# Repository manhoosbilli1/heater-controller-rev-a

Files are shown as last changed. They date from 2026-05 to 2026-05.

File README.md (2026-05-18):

# HEATER CONTROLLER REV_A

Battery-powered heater controller, 10 A switching, hierarchical schematic (ATtiny + OLED + dual-battery taps)

## At a Glance

- **Status**: Routed
- **Board size**: 47.24 x 45.82 mm
- **Layers**: 2
- **Components**: 75
- **Key ICs**:
  - U1: ATtiny3216-S
  - U2: DS18B20U
  - U3: TP4056
  - U4: INA234AxYBJ
  - U5,U6: TPS73001SF6
  - U7: TPS22997RYZR

## Schematic

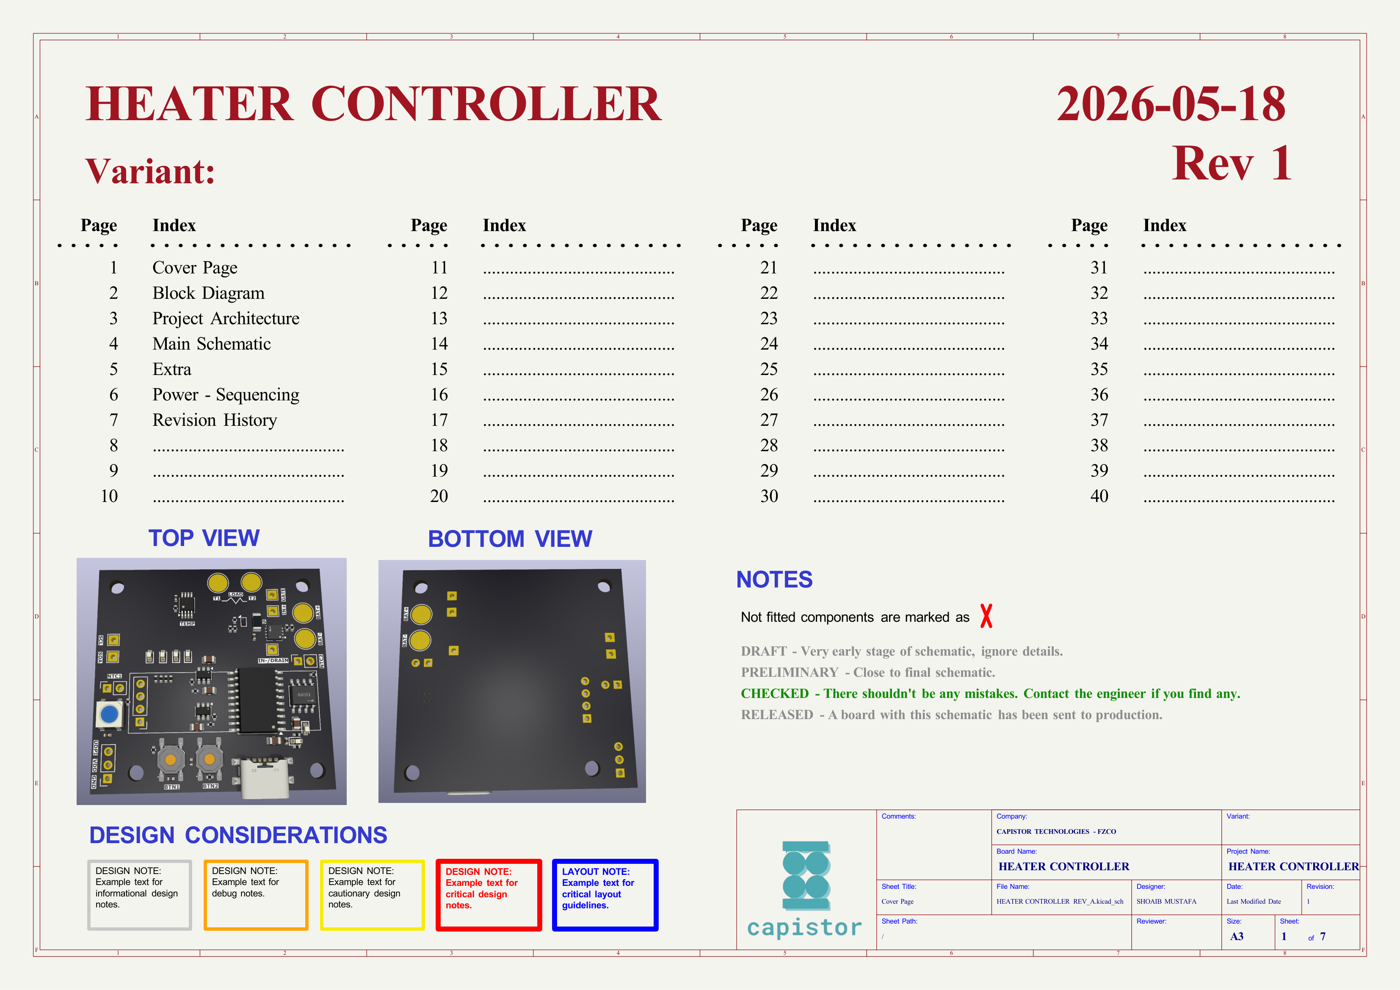
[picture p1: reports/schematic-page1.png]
Schematic


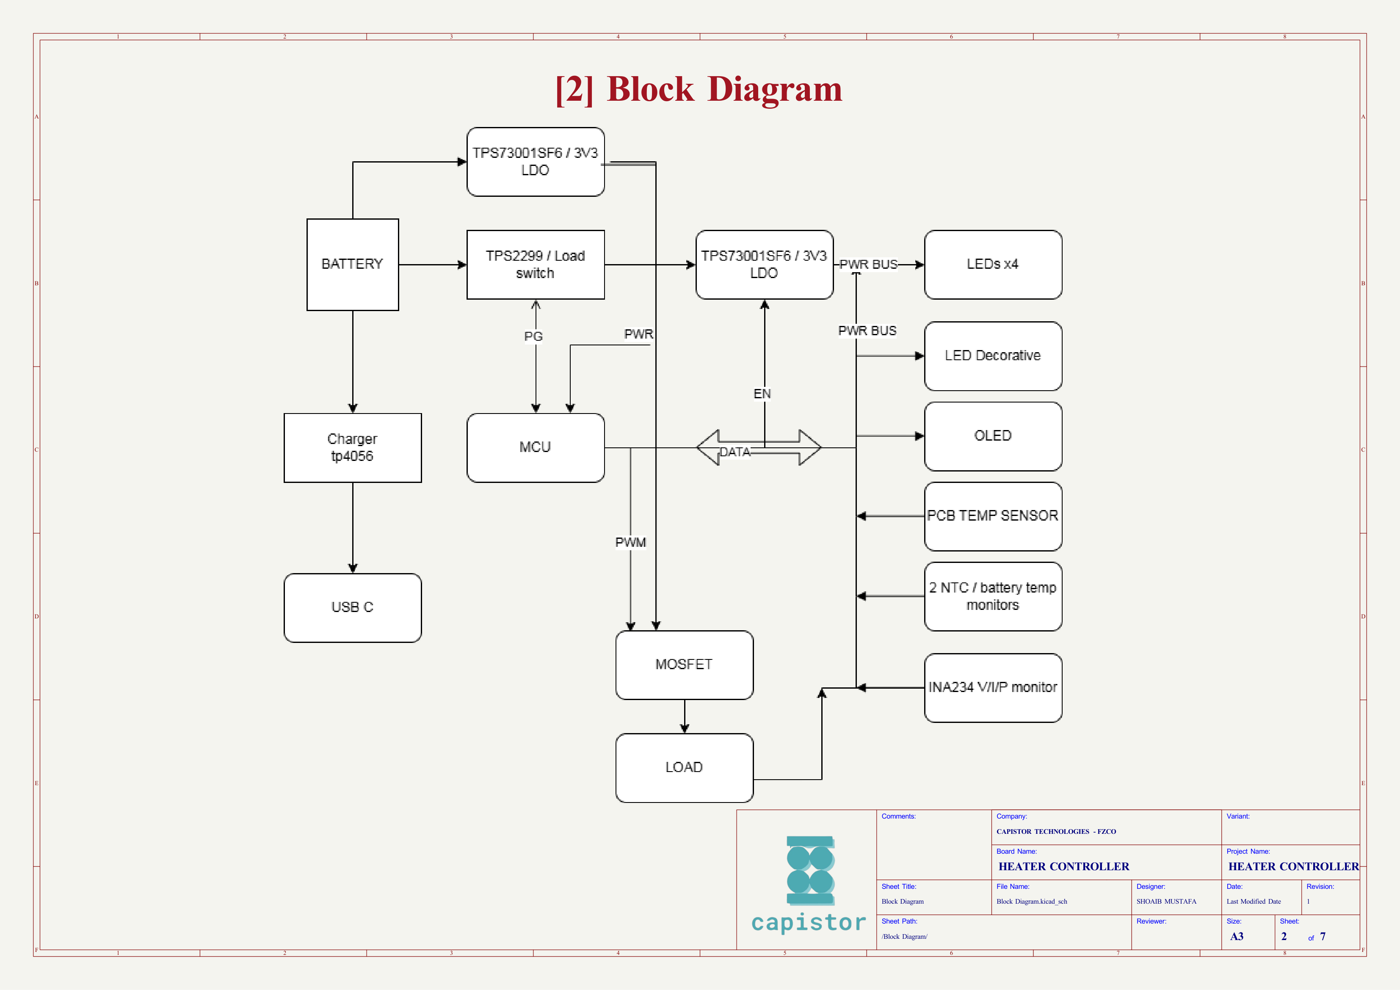
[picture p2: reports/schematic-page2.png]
Schematic


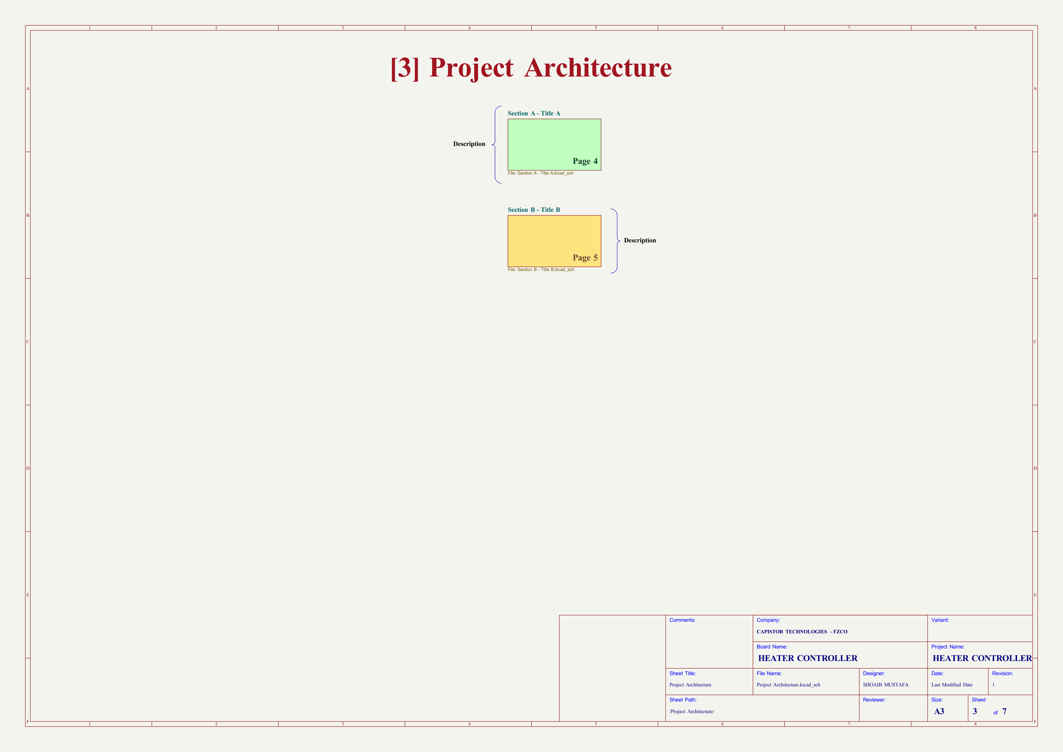
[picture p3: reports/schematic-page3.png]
Schematic


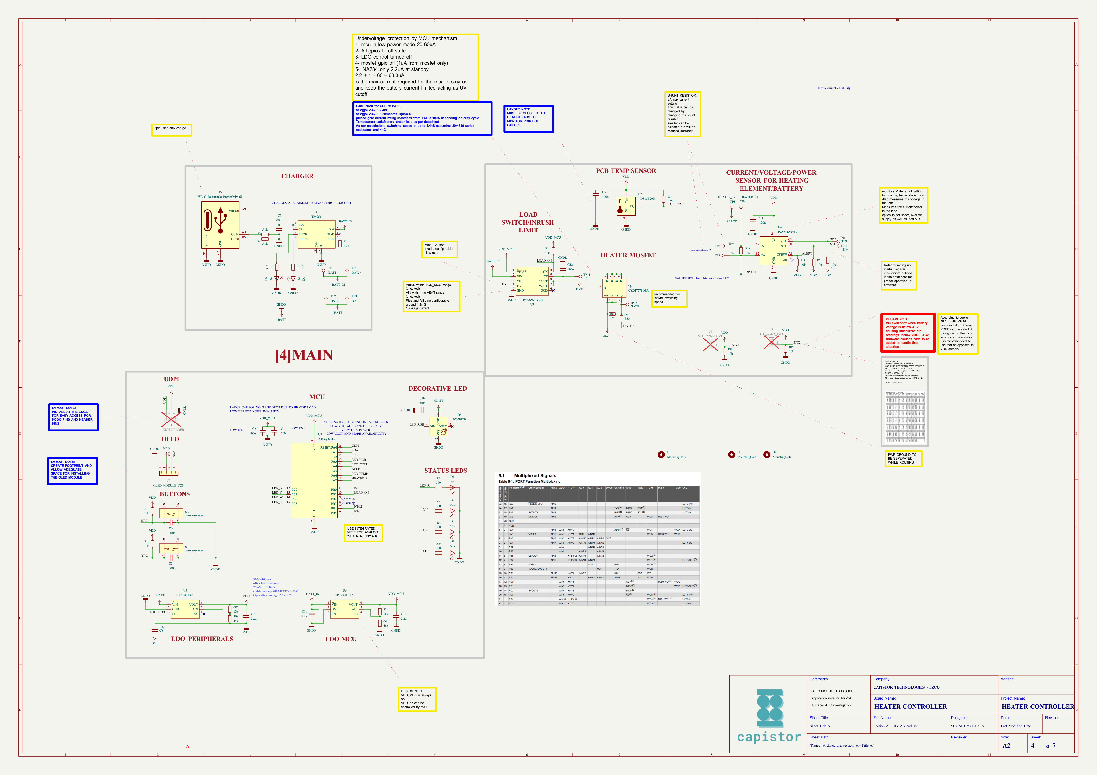
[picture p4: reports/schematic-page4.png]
Schematic


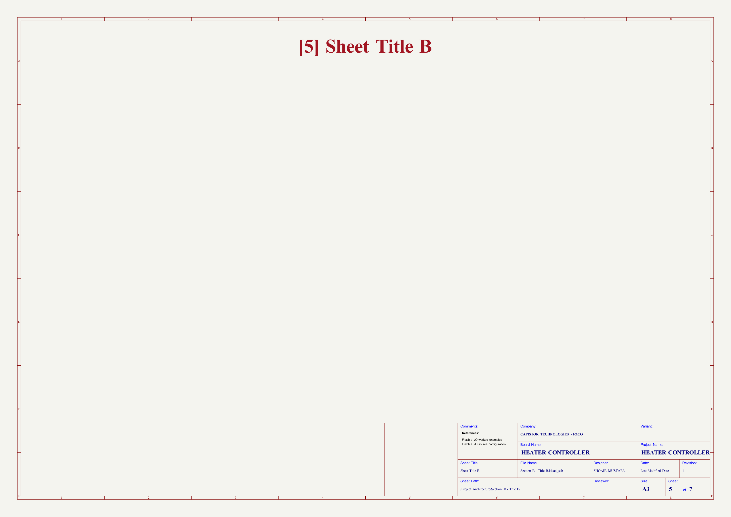
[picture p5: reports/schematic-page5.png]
Schematic


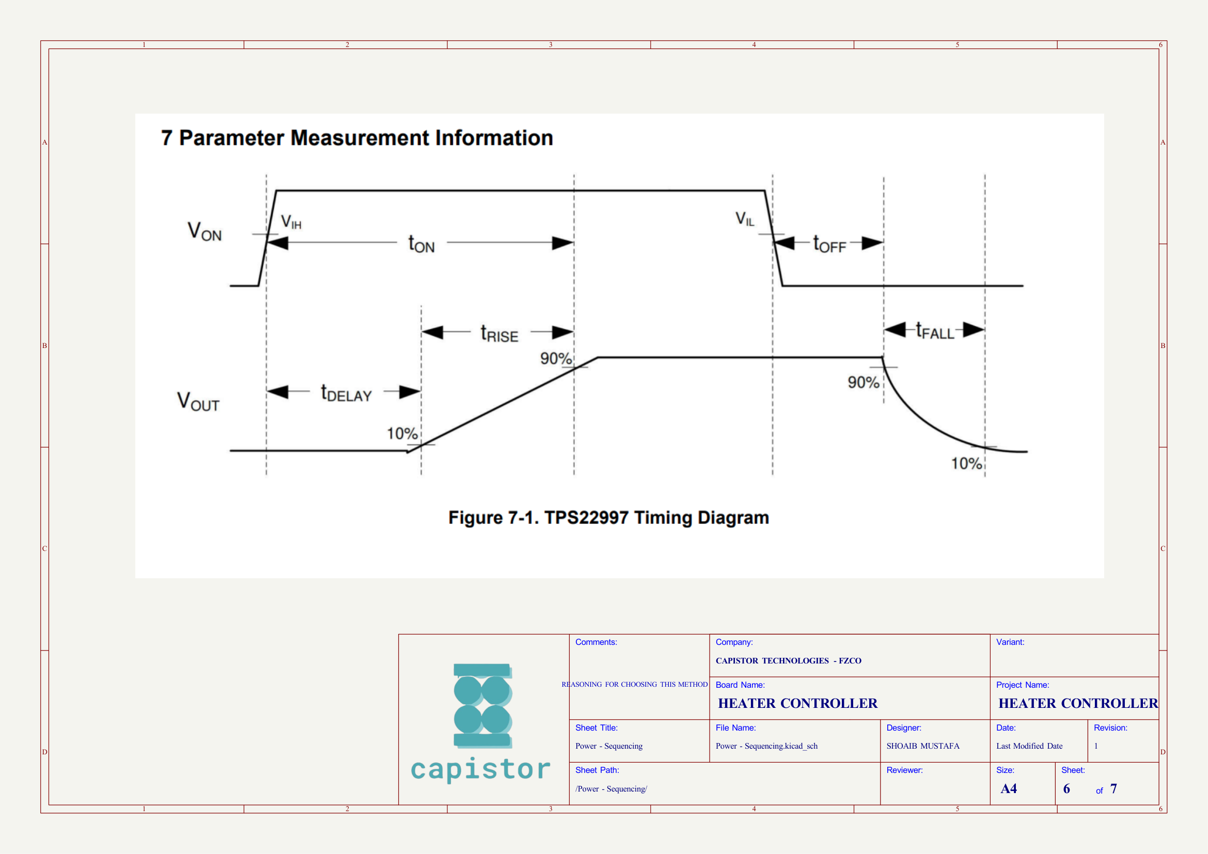
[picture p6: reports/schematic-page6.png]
Schematic


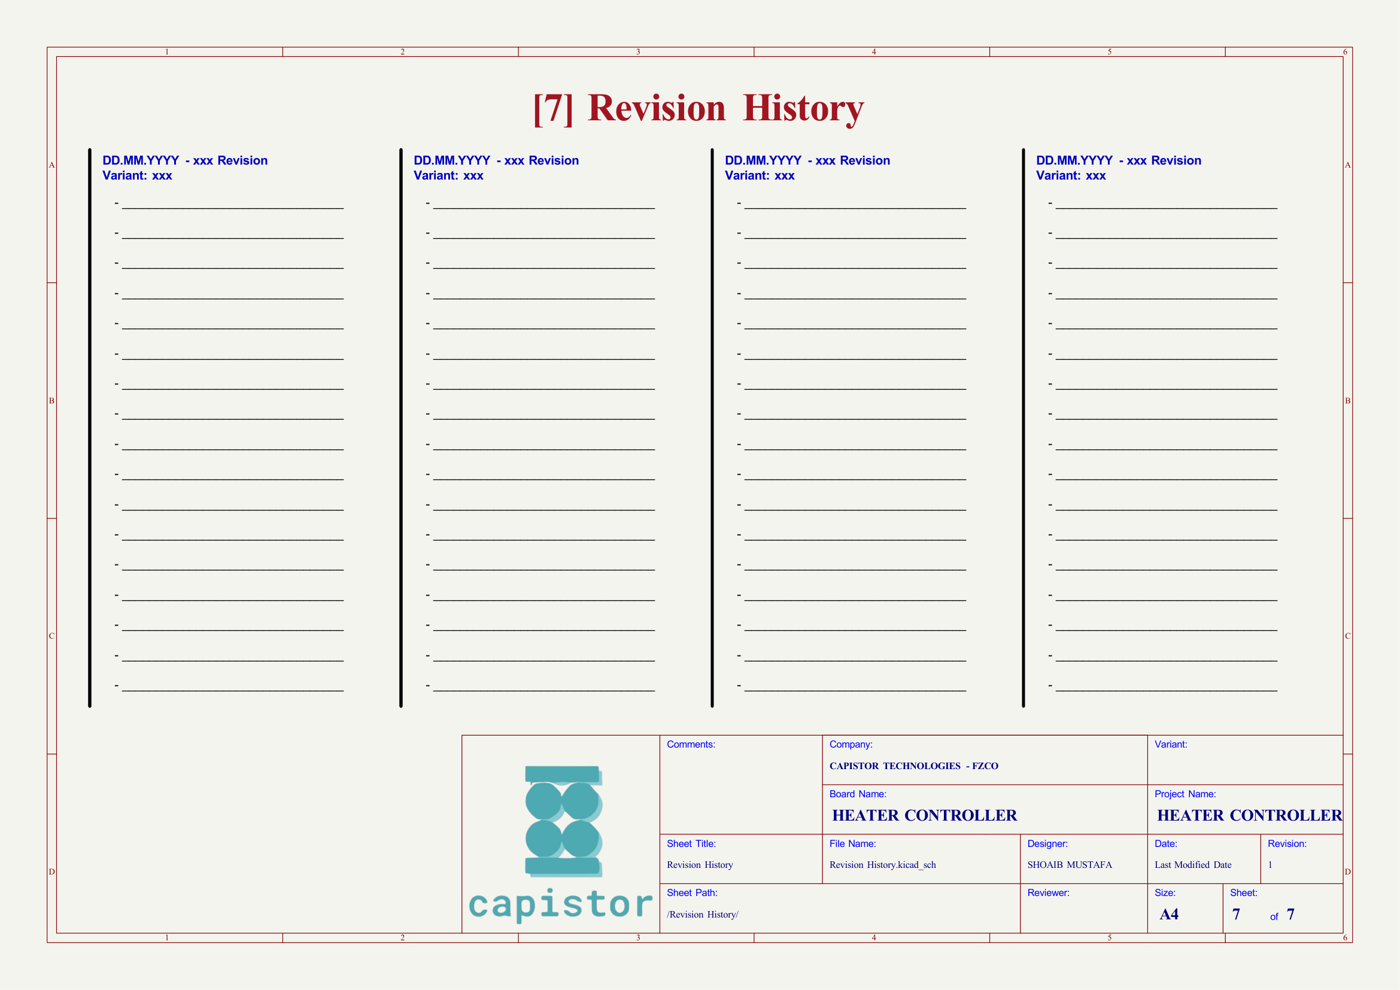
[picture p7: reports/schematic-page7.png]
Schematic


Full PDF: [reports/schematic.pdf](reports/schematic.pdf)

## Component Roles

- **ATtiny** (in hierarchical sub-sheets) - main MCU; reads temperature and PWM-drives the heater MOSFET
- **CSD17578Q3A** (Q2) - 30 V, 100 A, 1.8 m-Ohm N-channel MOSFET; switches the heater load directly (low Rds(on) keeps conduction losses small at 10 A)
- **WS2812B** (D5) - status RGB LED
- **USB-C** charging input (power-only, 6P)
- **Dual battery taps** (TP1-TP4: BAT1+, BAT1-, BAT2+, BAT2-) for parallel/series battery configurations
- **Heater output taps** (TP5/TP6: HEATER_T1, HEATER_T2)
- Hierarchical schematic split across: Block Diagram, Project Architecture, Power-Sequencing, and Section A/B sub-sheets

## PCB

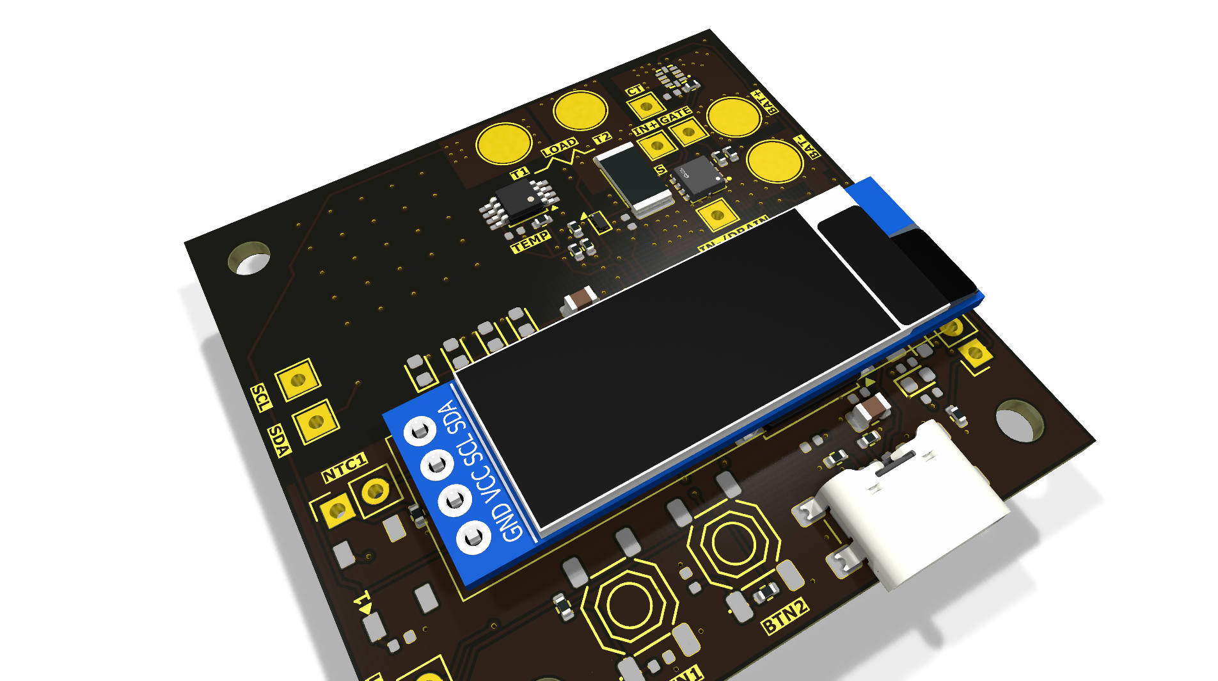
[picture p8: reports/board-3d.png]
3D top


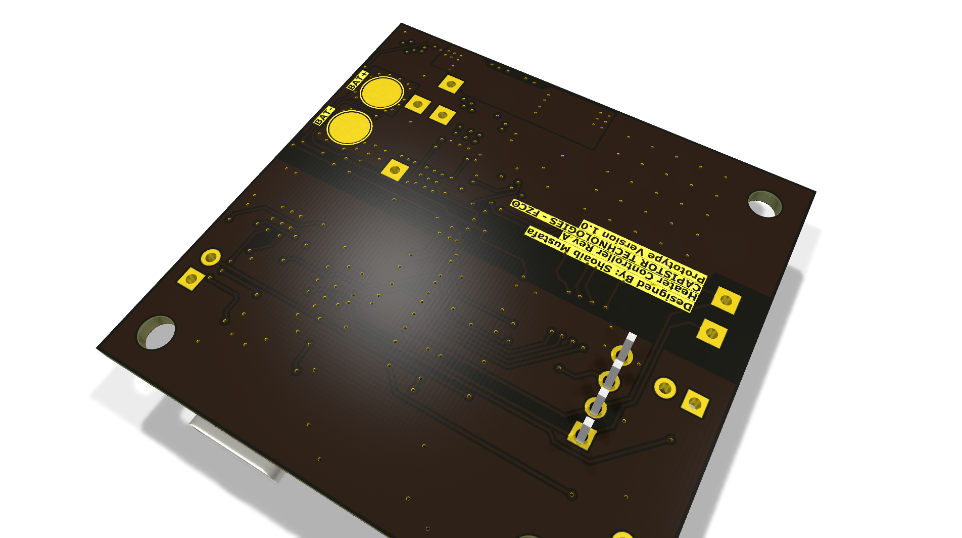
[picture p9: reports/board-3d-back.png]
3D bottom


**Top copper**

PCB top

**Bottom copper**

PCB bottom

## Bill of Materials

| Refs | Value | Footprint | Qty | MPN | LCSC |
|---|---|---|----:|-----|---|
| C1,C3-C7,C10,C12 | 100n | PCM_JLCPCB:C_0402 | 8 |  |  |
| C2 | 100u | Capacitor_SMD:C_0805_2012Metric | 1 |  | [C141660](https://www.lcsc.com/product-detail/_C141660.html) |
| C8,C9,C11,C13 | 2.2u | Capacitor_SMD:C_0805_2012Metric | 4 |  |  |
| D1,D6,D7 | Red | PCM_JLCPCB:D_0603 | 3 |  | [C2286](https://www.lcsc.com/product-detail/_C2286.html) |
| D2 | White | PCM_JLCPCB:D_0603 | 1 |  | [C2290](https://www.lcsc.com/product-detail/_C2290.html) |
| D3 | Yellow | PCM_JLCPCB:D_0603 | 1 |  | [C89811](https://www.lcsc.com/product-detail/_C89811.html) |
| D4 | Green | PCM_JLCPCB:D_0603 | 1 |  | [C122984](https://www.lcsc.com/product-detail/_C122984.html) |
| D5 | WS2812B | PCM_JLCPCB:LED_WS2812B_PLCC4_5.0x5.0mm_P3.2mm | 1 |  | [C22461793](https://www.lcsc.com/product-detail/_C22461793.html) |
| J5 | USB_C_Receptacle_PowerOnly_6P | Connector_USB:USB_C_Receptacle_GCT_USB4135-GF-A_6P_TopMnt_Horizontal | 1 |  |  |
| Q2 | CSD17578Q3A | mosfet_ti:PDFN3333-8_L3.1-W3.2-P0.65-LS3.4-BL | 1 |  |  |
| R1 | 4.7k | Resistor_SMD:R_0402_1005Metric | 1 |  |  |
| R2 | 1.2k | Resistor_SMD:R_0402_1005Metric | 1 |  |  |
| R3,R4 | 5.1k | Resistor_SMD:R_0402_1005Metric | 2 |  |  |
| R5,R6,R11,R12,R14,R15,R18,R19,R21,R24,R25 | 10k | Resistor_SMD:R_0402_1005Metric | 11 |  |  |
| R7-R10 | 330 | PCM_JLCPCB:R_0402 | 4 |  |  |
| R13 | 8m | Resistor_SMD:R_2512_6332Metric | 1 |  | [C2904240](https://www.lcsc.com/product-detail/_C2904240.html) |
| R16,R17 | 1k | PCM_JLCPCB:R_0402 | 2 |  |  |
| R20,R26 | 46k | Resistor_SMD:R_0402_1005Metric | 2 |  | [C3016791](https://www.lcsc.com/product-detail/_C3016791.html) |
| R23 | 330 | Resistor_SMD:R_0402_1005Metric | 1 |  |  |
| S1,S3 | Tactile Button, 160gf | PCM_JLCPCB:SW-SMD_4P-L5.1-W5.1-P3.70-LS6.5-TL-2 | 2 |  | [C318884](https://www.lcsc.com/product-detail/_C318884.html) |
| TP1 | BAT2+ | TestPoint:TestPoint_Pad_D4.0mm | 1 |  |  |
| TP2 | BAT2- | TestPoint:TestPoint_Pad_D4.0mm | 1 |  |  |
| TP3 | BAT1+ | TestPoint:TestPoint_Pad_D4.0mm | 1 |  |  |
| TP4 | BAT1- | TestPoint:TestPoint_Pad_D4.0mm | 1 |  |  |
| TP5 | HEATER_T2 | TestPoint:TestPoint_Pad_D4.0mm | 1 |  |  |
| TP6 | HEATER_T1 | TestPoint:TestPoint_Pad_D4.0mm | 1 |  |  |
| TP7,TP9,TP10 | IN+ | TestPoint:TestPoint_THTPad_2.0x2.0mm_Drill1.0mm | 3 |  |  |
| TP8 | IN- | TestPoint:TestPoint_THTPad_2.0x2.0mm_Drill1.0mm | 1 |  |  |
| TP11 | CT | TestPoint:TestPoint_THTPad_2.0x2.0mm_Drill1.0mm | 1 |  |  |
| TP12 | GATE | TestPoint:TestPoint_THTPad_2.0x2.0mm_Drill1.0mm | 1 |  |  |
| U1 | ATtiny3216-S | Package_SO:SOIC-20W_7.5x12.8mm_P1.27mm | 1 |  |  |
| U2 | DS18B20U | Package_SO:MSOP-8_3x3mm_P0.65mm | 1 |  |  |
| U3 | TP4056 | PCM_JLCPCB:ESOP-8_L4.9-W3.9-P1.27-LS6.0-BL-EP | 1 |  | [C16581](https://www.lcsc.com/product-detail/_C16581.html) |
| U4 | INA234AxYBJ | Package_BGA:Texas_DSBGA-8_0.705x1.468mm_Layout2x4_P0.4mm | 1 |  |  |
| U5,U6 | TPS73001SF6 | tps73001sf6:SOT-23-6_L2.9-W1.6-P0.95-LS2.8-BL | 2 |  |  |
| U7 | TPS22997RYZR | load_switch:UQFN-10_L2.0-W1.5-P0.50-TL | 1 |  |  |

_26 of 36 line items don't have an LCSC code in the schematic - search [LCSC](https://www.lcsc.com/) or [JLC parts search](https://jlcsearch.tscircuit.com/) by MPN or footprint when sourcing._

## Files

- `HEATER CONTROLLER REV_A.kicad_pro` - KiCad project
- `HEATER CONTROLLER REV_A.kicad_sch` - schematic source
- `HEATER CONTROLLER REV_A.kicad_pcb` - PCB layout source
- `reports/schematic.pdf` - full schematic (printable)
- `reports/bom.csv` - bill of materials
- `reports/pcb-top.svg`, `reports/pcb-bottom.svg` - copper artwork
- `reports/board-stats.json` - KiCad-generated board statistics

---

_Renders and metadata auto-generated by `Backup-KiCadProject.ps1` using KiCad 10.0._

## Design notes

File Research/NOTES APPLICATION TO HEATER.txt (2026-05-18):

MOSFET NOTES APPLICATION TO HEATER CONTROLLER 

- MUST be driven by low impedence source capable of sourcing and sinking current. does that mean it should be able to sink eqv charge by the mcu? 
- switching speeds are mostly high for all mosfets depended on carriers travel across band gap
- ON constant current not needed. just enough to charge the capacitors. 
- interested current conduction electrode (gate?) is isolated from the conducting path? yet because of the discharge resistor gate is not truly isolated. put optocoupler in between to achieve galvanic isolation. 

ISOLATION OF MCU AND HEATER 
- NO GALVANIC ISOLATION IS NEEDED. IT IS ONLY REQUIRE TO KEEP IT ELECTRICALLY ISOLATED
-For this the return current from the heater 10A should not flow through the mcu ground -for this we keep the mcu
-ground relatively higher resistance meaning short traces and the heater ground thicker

Exploring STAR ground technique to achieve electrical isolation of the ground:
-not applicable as it deals with providing a common ground point at same potential to various modules being connected to a common ground. 

Addressing the noise occurring due to switching 10A of current in the PCB:
- 

Addressing the thermal conductivity of the PCB traces and providing adequate dimensions for optimum performance: 
- Strategically place Thermal vias 
- consider inner planes just for heat transfer 
- consider gold plated pads instead of HASL for better connectivity and heat resistance
- consider focusing on junction temperature of each active component
- Consider location of heat source
- Consider creating a gradient to allow for natural heat flow from hot to cold
- Thermal resistance of PCB is determined by the material properties of the substrate and arrangement of copper elements in the board
- Keep high current traces short, wide for least thermal resistance and least voltage drop 
- consider measuring pcb thermal conductivity by guarded hot plate method; measuring temp of hot and cold surface of the pcb 
- Can also consider 3-omega measurement but a bit more involved
- Layer stackup can play a role in it. 
- Thermal resistance measurements can be carried out once the PCB is ordered as a prototype to improve in the next iteration 

power, inrush calculations and reasonings behind it. 

at 10Khz what would be the the saturation on the mosfet at 3.3V?
What would be the Rds(on) at that point? 
What is the inrush current of the heater material
What is the power dessipawted at that point

I(inrush current ) = Vmax / cold resistance = 4.2 / 0.199 ohm = 21A 

power drawn P = (Inrush current)^2 * (rdson + shunt resistor + material_resistance) = 21^2 * (0.199 + 0.004 + 0.004) = 1.65

Avoiding thermal runaway:
usually seen in applications powered by constant current source whereas the battery is a constant voltage source, as the temperature rises the resistance rises, as resistance rises Temperature of the trace rises, because current is constant more heat is generated which further increases the resistance and hence a condition is reached where the traces burn or explode: a thermal runaway

finding out if mosfet can handle the peak current P = Vds * Id = 4.2 * 21 = 88 W?

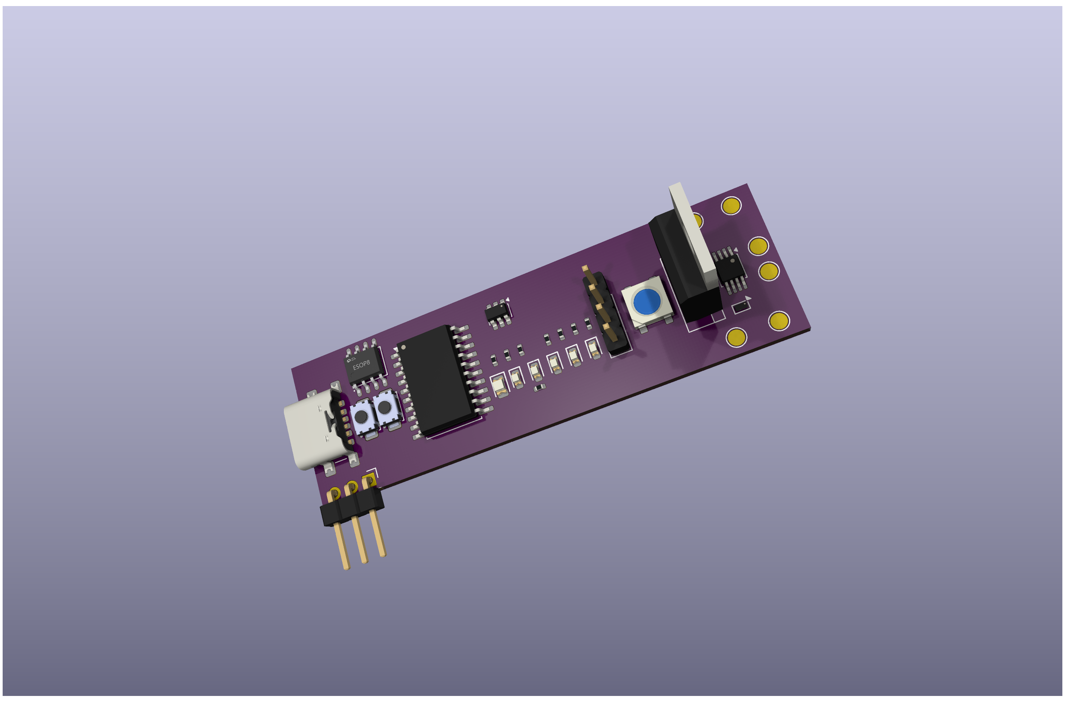
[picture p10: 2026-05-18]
Images/PRELIMINARY PLACEMENT.png

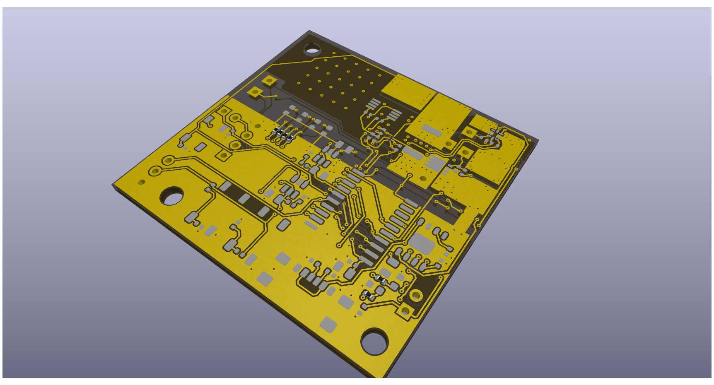
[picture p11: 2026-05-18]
Images/HEATER CONTROLLER REV_A_Checked_prototype_v1.0_front_copper_plane_without_models.png

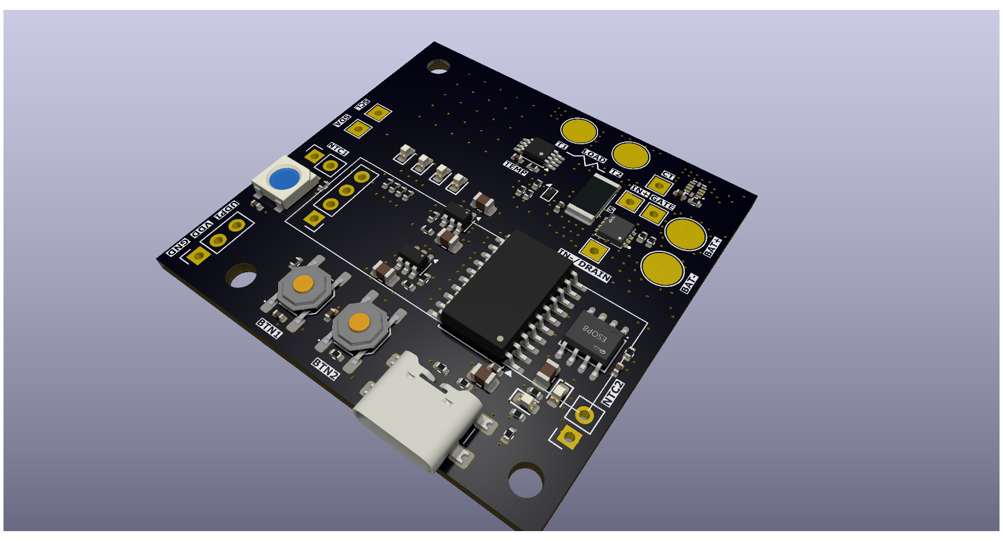
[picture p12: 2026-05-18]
Images/HEATER CONTROLLER REV_A_Checked_prototype_v1.0_front.png

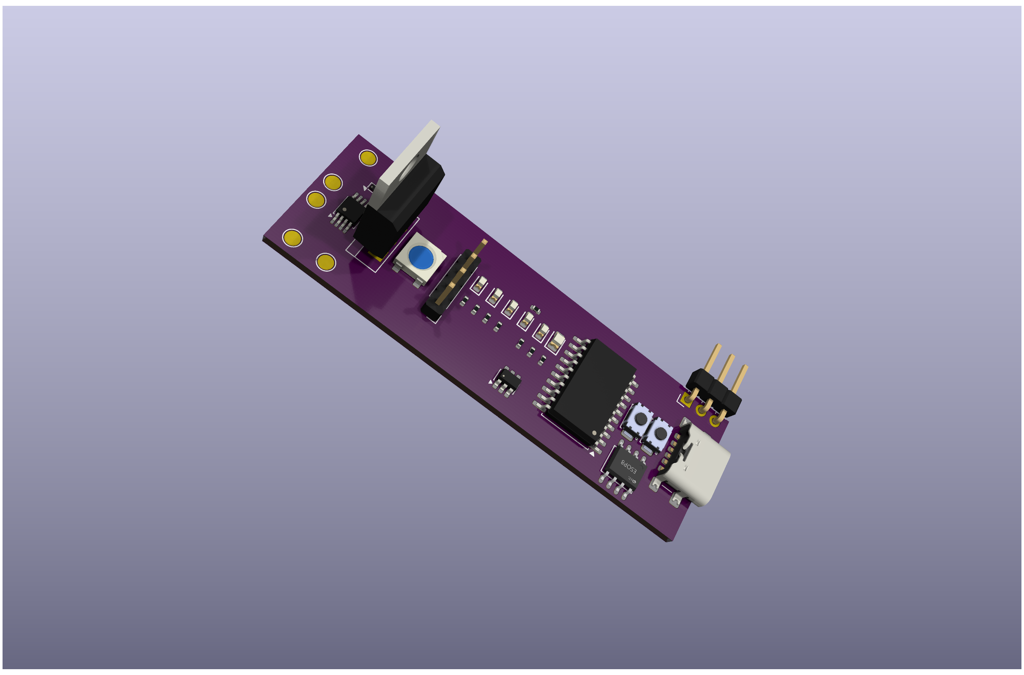
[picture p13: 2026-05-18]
Images/PRELIMINARY PLACEMENT FRONT .png

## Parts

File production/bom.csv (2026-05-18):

Designator | Footprint | Quantity | Value | LCSC Part #
C1, C10, C12, C3, C4, C5, C6 | C_0402 | 7 | 100n
C11, C13, C8, C9 | 0805 | 4 | 2.2u
C2 | 0805 | 1 | 100u
C7 | C_0402 | 1 | 100u
D1, D6, D7 | D_0603 | 3 | Red | C2286
D2 | D_0603 | 1 | White | C2290
D3 | D_0603 | 1 | Yellow | C89811
D4 | D_0603 | 1 | Green | C122984
D5 | LED_WS2812B_PLCC4_5.0x5.0mm_P3.2mm | 1 | WS2812B | C22461793
J5 | USB_C_Receptacle_GCT_USB4135-GF-A_6P_TopMnt_Horizontal | 1 | USB_C_Receptacle_PowerOnly_6P
Q2 | PDFN3333-8_L3.1-W3.2-P0.65-LS3.4-BL | 1 | CSD17578Q3A | C205986
R1 | 0402 | 1 | 4.7k
R10, R7, R8, R9 | R_0402 | 4 | 330
R11, R12, R14, R15, R18, R19, R21, R24, R25, R5, R6 | 0402 | 11 | 10k
R13 | 2512 | 1 | 8m | C2904240
R16, R17 | R_0402 | 2 | 1k
R2 | 0402 | 1 | 1.2k
R20, R26 | 0402 | 2 | 46k | C3016791
R23 | 0402 | 1 | 330
R3, R4 | 0402 | 2 | 5.1k
S1, S3 | SW-SMD_4P-L5.1-W5.1-P3.70-LS6.5-TL-2 | 2 | Tactile Button, 160gf | C318884
TP1 | TestPoint_Pad_D4.0mm | 1 | BAT2+
TP10, TP7, TP9 | TestPoint_THTPad_2.0x2.0mm_Drill1.0mm | 3 | IN+
TP11 | TestPoint_THTPad_2.0x2.0mm_Drill1.0mm | 1 | CT
TP12 | TestPoint_THTPad_2.0x2.0mm_Drill1.0mm | 1 | GATE
TP2 | TestPoint_Pad_D4.0mm | 1 | BAT2-
TP3 | TestPoint_Pad_D4.0mm | 1 | BAT1+
TP4 | TestPoint_Pad_D4.0mm | 1 | BAT1-
TP5 | TestPoint_Pad_D4.0mm | 1 | HEATER_T2
TP6 | TestPoint_Pad_D4.0mm | 1 | HEATER_T1
TP8 | TestPoint_THTPad_2.0x2.0mm_Drill1.0mm | 1 | IN-
U1 | SOIC-20W_7.5x12.8mm_P1.27mm | 1 | ATtiny3216-S
U2 | MSOP-8_3x3mm_P0.65mm | 1 | DS18B20U
U3 | ESOP-8_L4.9-W3.9-P1.27-LS6.0-BL-EP | 1 | TP4056 | C16581
U4 | Texas_DSBGA-8_0.705x1.468mm_Layout2x4_P0.4mm | 1 | INA234AxYBJ
U5, U6 | SOT-23-6_L2.9-W1.6-P0.95-LS2.8-BL | 2 | TPS73001SF6 | C2915259
U7 | UQFN-10_L2.0-W1.5-P0.50-TL | 1 | TPS22997RYZR | C17286840

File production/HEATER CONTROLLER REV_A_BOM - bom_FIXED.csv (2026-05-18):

Designator | Footprint | Quantity | Value | LCSC Part #
C1, C10, C12, C3, C4, C5, C6 | C_0402 | 7 | 100n
C11, C13, C8, C9 | C_0805 | 4 | 2.2u
C2 | C_0805 | 1 | 100u
C7 | C_0402 | 1 | 100n
D1, D6, D7 | D_0603 | 3 | Red | C2286
D2 | D_0603 | 1 | White | C2290
D3 | D_0603 | 1 | Yellow | C89811
D4 | D_0603 | 1 | Green | C122984
D5 | LED_WS2812B_PLCC4_5.0x5.0mm_P3.2mm | 1 | WS2812B | C22461793
J5 | USB_C_Receptacle_GCT_USB4135-GF-A_6P_TopMnt_Horizontal | 1 | USB_C_Receptacle_PowerOnly_6P | C2927028
Q2 | PDFN3333-8_L3.1-W3.2-P0.65-LS3.4-BL | 1 | CSD17578Q3A | C205986
R1 | R_0402 | 1 | 4.7k
R10, R7, R8, R9 | R_0402 | 4 | 330
R11, R12, R14, R15, R18, R19, R21, R24, R25, R5, R6 | R_0402 | 11 | 10k
R13 | R_2512 | 1 | 8m | C2904240
R16, R17 | R_0402 | 2 | 1k
R2 | R_0402 | 1 | 1.2k
R20, R26 | R_0402 | 2 | 46k | C3016791
R23 | R_0402 | 1 | 330
R3, R4 | R_0402 | 2 | 5.1k
S1, S3 | SW-SMD_4P-L5.1-W5.1-P3.70-LS6.5-TL-2 | 2 | Tactile Button, 160gf | C318884
U1 | SOIC-20W_7.5x12.8mm_P1.27mm | 1 | ATtiny3216-S | C609661
U2 | MSOP-8_3x3mm_P0.65mm | 1 | DS18B20U | C4371066
U3 | ESOP-8_L4.9-W3.9-P1.27-LS6.0-BL-EP | 1 | TP4056 | C16581
U4 | Texas_DSBGA-8_0.705x1.468mm_Layout2x4_P0.4mm | 1 | INA234AxYBJ | C4371066
U5, U6 | SOT-23-6_L2.9-W1.6-P0.95-LS2.8-BL | 2 | TPS73001SF6 | C2915259
U7 | UQFN-10_L2.0-W1.5-P0.50-TL | 1 | TPS22997RYZR | C17286840

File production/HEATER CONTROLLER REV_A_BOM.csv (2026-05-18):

Reference | Value | Datasheet | Footprint | Qty | DNP
C1,C3,C4,C5,C6,C10,C12 | 100n | ~ | PCM_JLCPCB:C_0402 | 7
C2,C7 | 100u | ~ | Capacitor_SMD:C_0805_2012Metric,PCM_JLCPCB:C_0402 | 2
C8,C9,C11,C13 | 2.2u | ~ | Capacitor_SMD:C_0805_2012Metric | 4
D1,D6,D7 | Red | https://www.lcsc.com/datasheet/lcsc_datasheet_1810231112_Hubei-KENTO-Elec-KT-0603R_C2286.pdf | PCM_JLCPCB:D_0603 | 3
D2 | White | https://www.lcsc.com/datasheet/lcsc_datasheet_2305091500_Hubei-KENTO-Elec-KT-0603W_C2290.pdf | PCM_JLCPCB:D_0603 | 1
D3 | Yellow | https://www.lcsc.com/datasheet/lcsc_datasheet_2008201033_Foshan-NationStar-Optoelectronics-NCD0603Y2_C89811.pdf | PCM_JLCPCB:D_0603 | 1
D4 | Green | https://www.lcsc.com/datasheet/lcsc_datasheet_1806151820_Hubei-KENTO-Elec-KT-0805G_C2297.pdf | PCM_JLCPCB:D_0603 | 1
D5 | WS2812B | https://wmsc.lcsc.com/wmsc/upload/file/pdf/v2/lcsc/2406131538_XINGLIGHT-XL-5050RGBC-WS2812B-S_C22461793.pdf | PCM_JLCPCB:LED_WS2812B_PLCC4_5.0x5.0mm_P3.2mm | 1
J5 | USB_C_Receptacle_PowerOnly_6P | https://www.usb.org/sites/default/files/documents/usb_type-c.zip | Connector_USB:USB_C_Receptacle_GCT_USB4135-GF-A_6P_TopMnt_Horizontal | 1
Q2 | CSD17578Q3A | https://lcsc.com/product-detail/MOSFET_TI_CSD17578Q3A_CSD17578Q3A_C205986.html | mosfet_ti:PDFN3333-8_L3.1-W3.2-P0.65-LS3.4-BL | 1
R1 | 4.7k | ~ | Resistor_SMD:R_0402_1005Metric | 1
R2 | 1.2k | ~ | Resistor_SMD:R_0402_1005Metric | 1
R3,R4 | 5.1k | ~ | Resistor_SMD:R_0402_1005Metric | 2
R5,R6,R11,R12,R14,R15,R18,R19,R21,R24,R25 | 10k | ~ | Resistor_SMD:R_0402_1005Metric | 11
R7,R8,R9,R10,R23 | 330 | ~ | PCM_JLCPCB:R_0402,Resistor_SMD:R_0402_1005Metric | 5
R13 | 8m | https://jlcpcb.com/api/file/downloadByFileSystemAccessId/8589839167539470336 | Resistor_SMD:R_2512_6332Metric | 1
R16,R17 | 1k | ~ | PCM_JLCPCB:R_0402 | 2
R20,R26 | 46k | ~ | Resistor_SMD:R_0402_1005Metric | 2
S1,S3 | Tactile Button, 160gf | https://www.lcsc.com/datasheet/lcsc_datasheet_2304140030_XKB-Connection-TS-1187A-B-A-B_C318884.pdf | PCM_JLCPCB:SW-SMD_4P-L5.1-W5.1-P3.70-LS6.5-TL-2 | 2
TP1 | BAT2+ | ~ | TestPoint:TestPoint_Pad_D4.0mm | 1
TP2 | BAT2- | ~ | TestPoint:TestPoint_Pad_D4.0mm | 1
TP3 | BAT1+ | ~ | TestPoint:TestPoint_Pad_D4.0mm | 1
TP4 | BAT1- | ~ | TestPoint:TestPoint_Pad_D4.0mm | 1
TP5 | HEATER_T2 | ~ | TestPoint:TestPoint_Pad_D4.0mm | 1
TP6 | HEATER_T1 | ~ | TestPoint:TestPoint_Pad_D4.0mm | 1
TP7,TP9,TP10 | IN+ | ~ | TestPoint:TestPoint_THTPad_2.0x2.0mm_Drill1.0mm | 3
TP8 | IN- | ~ | TestPoint:TestPoint_THTPad_2.0x2.0mm_Drill1.0mm | 1
TP11 | CT | ~ | TestPoint:TestPoint_THTPad_2.0x2.0mm_Drill1.0mm | 1
TP12 | GATE | ~ | TestPoint:TestPoint_THTPad_2.0x2.0mm_Drill1.0mm | 1
U1 | ATtiny3216-S | http://ww1.microchip.com/downloads/en/DeviceDoc/ATtiny3216_ATtiny1616-data-sheet-40001997B.pdf | Package_SO:SOIC-20W_7.5x12.8mm_P1.27mm | 1
U2 | DS18B20U | http://datasheets.maximintegrated.com/en/ds/DS18B20.pdf | Package_SO:MSOP-8_3x3mm_P0.65mm | 1
U3 | TP4056 | https://www.lcsc.com/datasheet/lcsc_datasheet_1809261820_TOPPOWER-Nanjing-Extension-Microelectronics-TP4056-42-ESOP8_C16581.pdf | PCM_JLCPCB:ESOP-8_L4.9-W3.9-P1.27-LS6.0-BL-EP | 1
U4 | INA234AxYBJ | https://www.ti.com/lit/ds/symlink/ina234.pdf | Package_BGA:Texas_DSBGA-8_0.705x1.468mm_Layout2x4_P0.4mm | 1
U5,U6 | TPS73001SF6 |  | tps73001sf6:SOT-23-6_L2.9-W1.6-P0.95-LS2.8-BL | 2
U7 | TPS22997RYZR |  | load_switch:UQFN-10_L2.0-W1.5-P0.50-TL | 1

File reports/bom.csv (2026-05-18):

Refs | Value | Footprint | Qty | Description | Mfr | MPN | LCSC
C1,C3-C7,C10,C12 | 100n | PCM_JLCPCB:C_0402 | 8 | Unpolarized capacitor, small symbol
C2 | 100u | Capacitor_SMD:C_0805_2012Metric | 1 | Unpolarized capacitor, small symbol |  |  | C141660
C8,C9,C11,C13 | 2.2u | Capacitor_SMD:C_0805_2012Metric | 4 | Unpolarized capacitor, small symbol
D1,D6,D7 | Red | PCM_JLCPCB:D_0603 | 3 | -40°C~+85°C Red 0603 LED Indication - Discrete ROHS | Hubei KENTO Elec |  | C2286
D2 | White | PCM_JLCPCB:D_0603 | 1 | White 0603 LED Indication - Discrete ROHS | Hubei KENTO Elec |  | C2290
D3 | Yellow | PCM_JLCPCB:D_0603 | 1 | 25mA 100mcd~220mcd Colorless transparent lens 586nm~595nm -30°C~+85°C Yellow 130° 65mW 1.6V~2.6V 0603 LED Indication - Discrete ROHS | Foshan NationStar Optoelectronics |  | C89811
D4 | Green | PCM_JLCPCB:D_0603 | 1 | Emerald 0805 LED Indication - Discrete ROHS | Hubei KENTO Elec |  | C122984
D5 | WS2812B | PCM_JLCPCB:LED_WS2812B_PLCC4_5.0x5.0mm_P3.2mm | 1 | RGB LED with integrated controller |  |  | C22461793
J5 | USB_C_Receptacle_PowerOnly_6P | Connector_USB:USB_C_Receptacle_GCT_USB4135-GF-A_6P_TopMnt_Horizontal | 1 | USB Power-Only 6P Type-C Receptacle connector
Q2 | CSD17578Q3A | mosfet_ti:PDFN3333-8_L3.1-W3.2-P0.65-LS3.4-BL | 1
R1 | 4.7k | Resistor_SMD:R_0402_1005Metric | 1 | Resistor, small symbol
R2 | 1.2k | Resistor_SMD:R_0402_1005Metric | 1 | Resistor, small symbol
R3,R4 | 5.1k | Resistor_SMD:R_0402_1005Metric | 2 | Resistor, small symbol
R5,R6,R11,R12,R14,R15,R18,R19,R21,R24,R25 | 10k | Resistor_SMD:R_0402_1005Metric | 11 | Resistor, small symbol
R7-R10 | 330 | PCM_JLCPCB:R_0402 | 4 | Resistor, small symbol
R13 | 8m | Resistor_SMD:R_2512_6332Metric | 1 | Resistor, small symbol |  |  | C2904240
R16,R17 | 1k | PCM_JLCPCB:R_0402 | 2 | Resistor, small symbol
R20,R26 | 46k | Resistor_SMD:R_0402_1005Metric | 2 | Resistor, small symbol |  |  | C3016791
R23 | 330 | Resistor_SMD:R_0402_1005Metric | 1 | Resistor, small symbol
S1,S3 | Tactile Button, 160gf | PCM_JLCPCB:SW-SMD_4P-L5.1-W5.1-P3.70-LS6.5-TL-2 | 2 | None Without 50mA 5.1mm 100000 Times 160gf 12V 5.1mm 1.5mm Round Button Standing paste SPST SMD Tactile Switches ROHS | XKB Connectivity |  | C318884
TP1 | BAT2+ | TestPoint:TestPoint_Pad_D4.0mm | 1 | test point
TP2 | BAT2- | TestPoint:TestPoint_Pad_D4.0mm | 1 | test point
TP3 | BAT1+ | TestPoint:TestPoint_Pad_D4.0mm | 1 | test point
TP4 | BAT1- | TestPoint:TestPoint_Pad_D4.0mm | 1 | test point
TP5 | HEATER_T2 | TestPoint:TestPoint_Pad_D4.0mm | 1 | test point
TP6 | HEATER_T1 | TestPoint:TestPoint_Pad_D4.0mm | 1 | test point
TP7,TP9,TP10 | IN+ | TestPoint:TestPoint_THTPad_2.0x2.0mm_Drill1.0mm | 3 | test point
TP8 | IN- | TestPoint:TestPoint_THTPad_2.0x2.0mm_Drill1.0mm | 1 | test point
TP11 | CT | TestPoint:TestPoint_THTPad_2.0x2.0mm_Drill1.0mm | 1 | test point
TP12 | GATE | TestPoint:TestPoint_THTPad_2.0x2.0mm_Drill1.0mm | 1 | test point
U1 | ATtiny3216-S | Package_SO:SOIC-20W_7.5x12.8mm_P1.27mm | 1 | 20MHz, 32kB Flash, 2kB SRAM, 256B EEPROM, SOIC-20
U2 | DS18B20U | Package_SO:MSOP-8_3x3mm_P0.65mm | 1 | Programmable Resolution 1-Wire Digital Thermometer MSOP-8
U3 | TP4056 | PCM_JLCPCB:ESOP-8_L4.9-W3.9-P1.27-LS6.0-BL-EP | 1 | ESOP-8 Battery Management ROHS | TOPPOWER(Nanjing Extension Microelectronics) |  | C16581
U4 | INA234AxYBJ | Package_BGA:Texas_DSBGA-8_0.705x1.468mm_Layout2x4_P0.4mm | 1 | Bidirectional Current/Voltage/Power Monitor (0-28V) With I2C Interface, DSBGA-8
U5,U6 | TPS73001SF6 | tps73001sf6:SOT-23-6_L2.9-W1.6-P0.95-LS2.8-BL | 2
U7 | TPS22997RYZR | load_switch:UQFN-10_L2.0-W1.5-P0.50-TL | 1

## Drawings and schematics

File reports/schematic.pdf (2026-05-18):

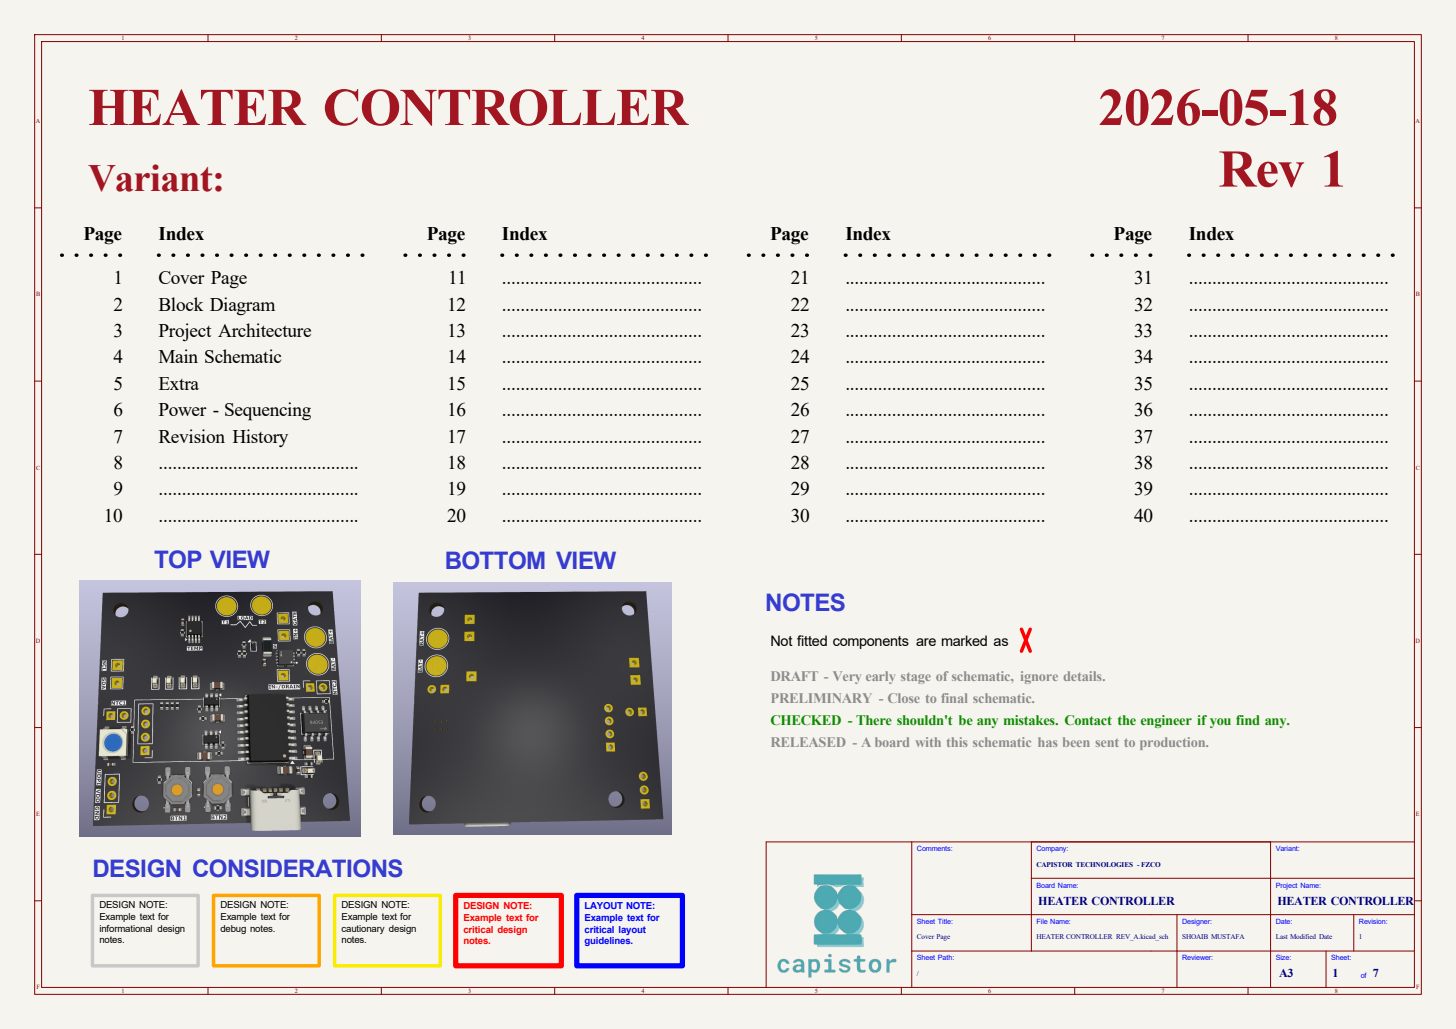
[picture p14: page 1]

........................................... RELEASED - A board with this schematic has been sent to production.

Not fitted components are marked as

DRAFT - Very early stage of schematic, ignore details.

CHECKED - There shouldn't be any mistakes. Contact the engineer if you find any.

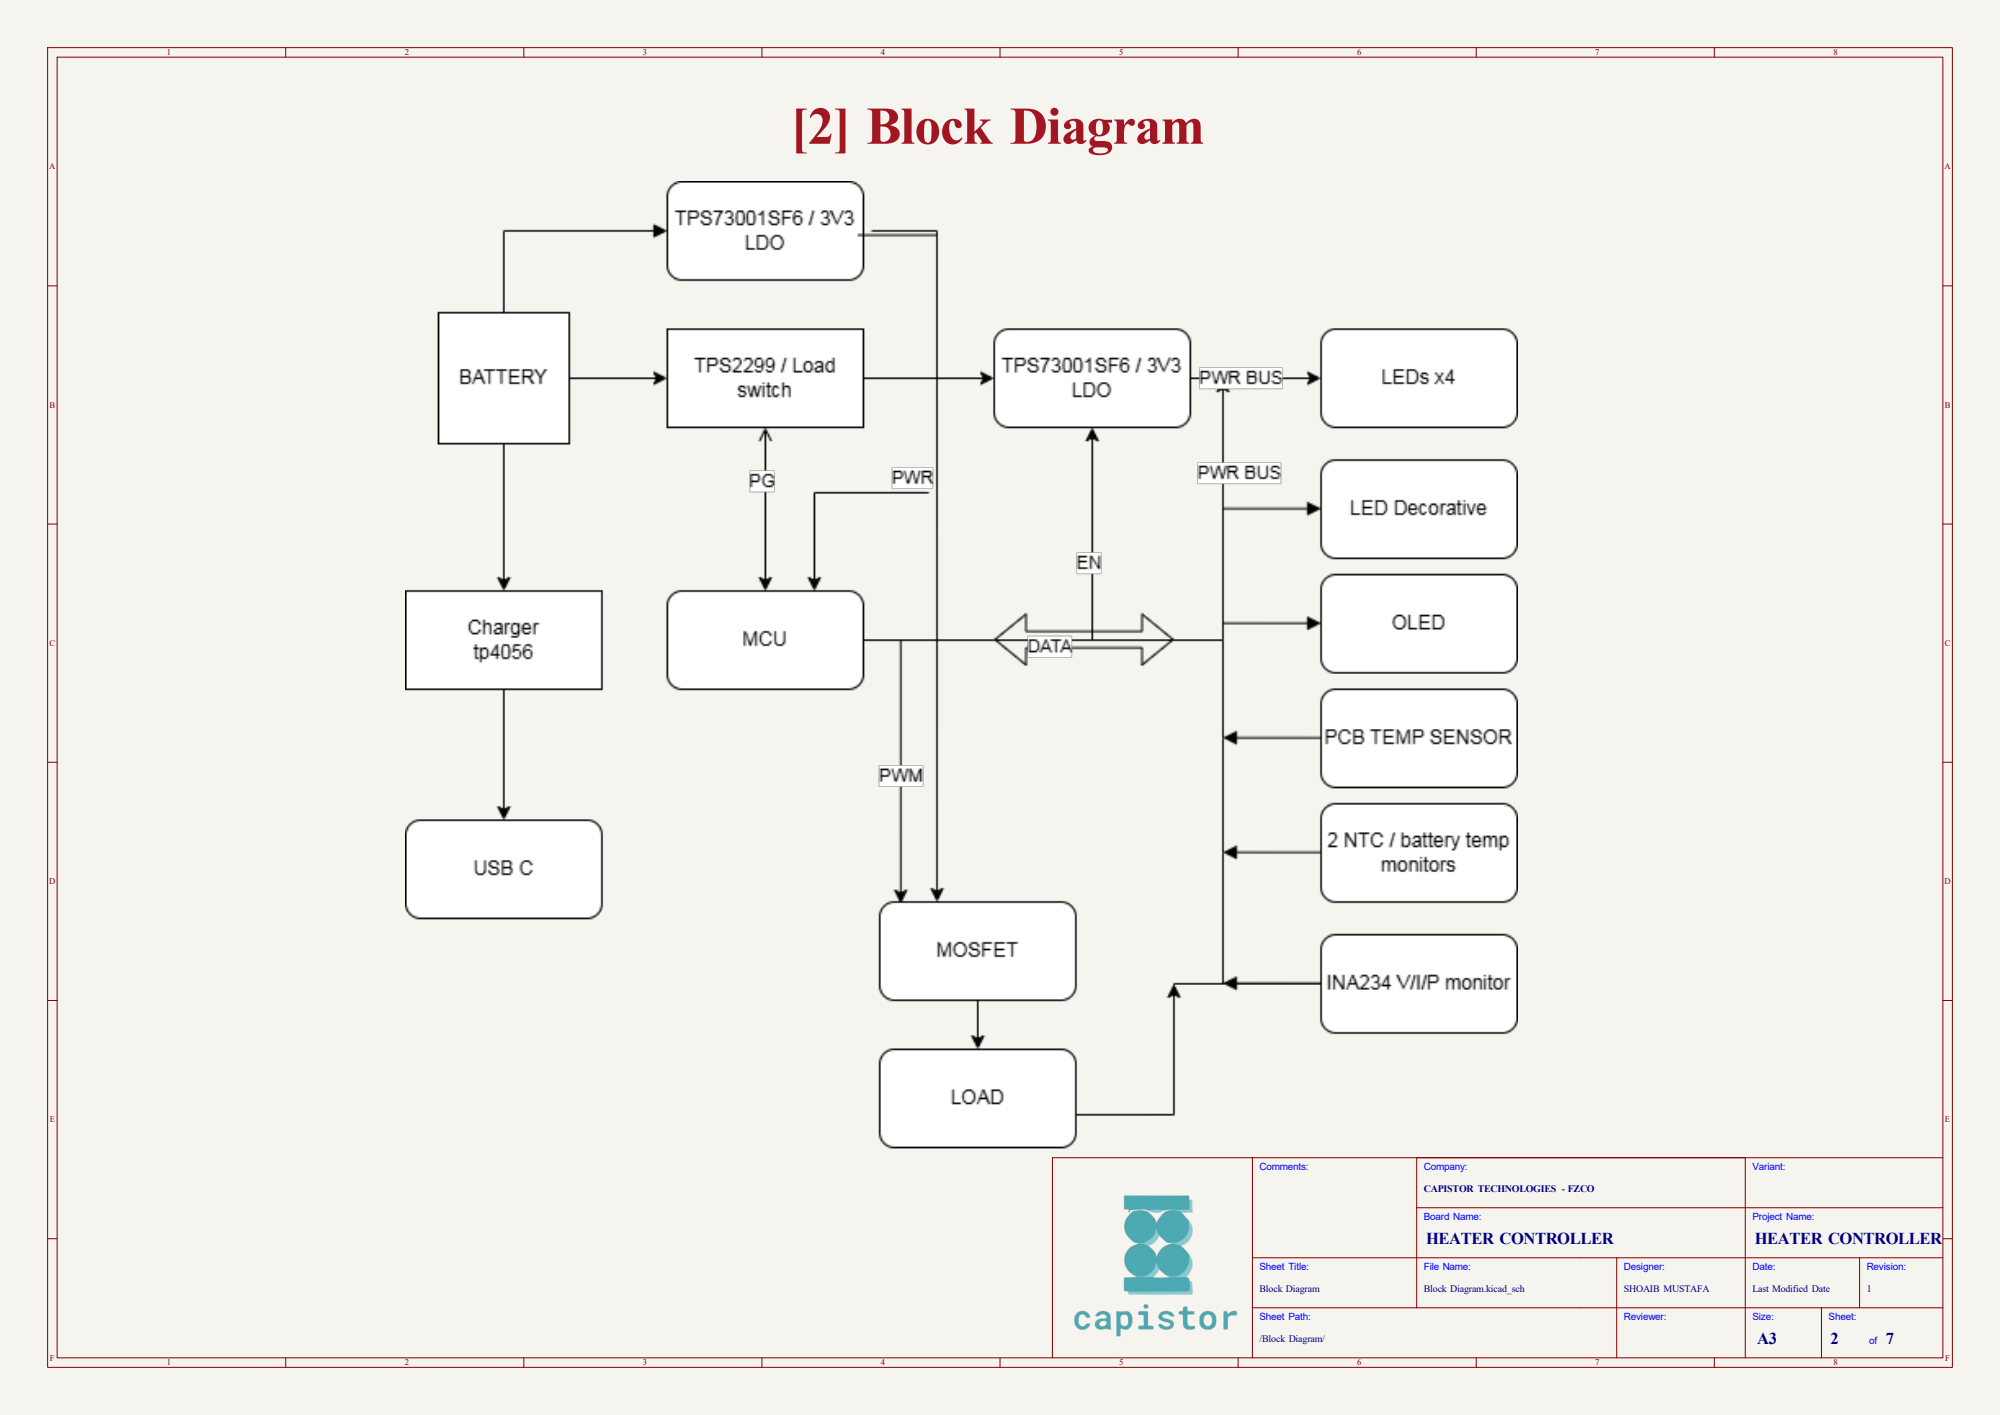
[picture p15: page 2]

/Block Diagram/ Sheet Path: Block Diagram

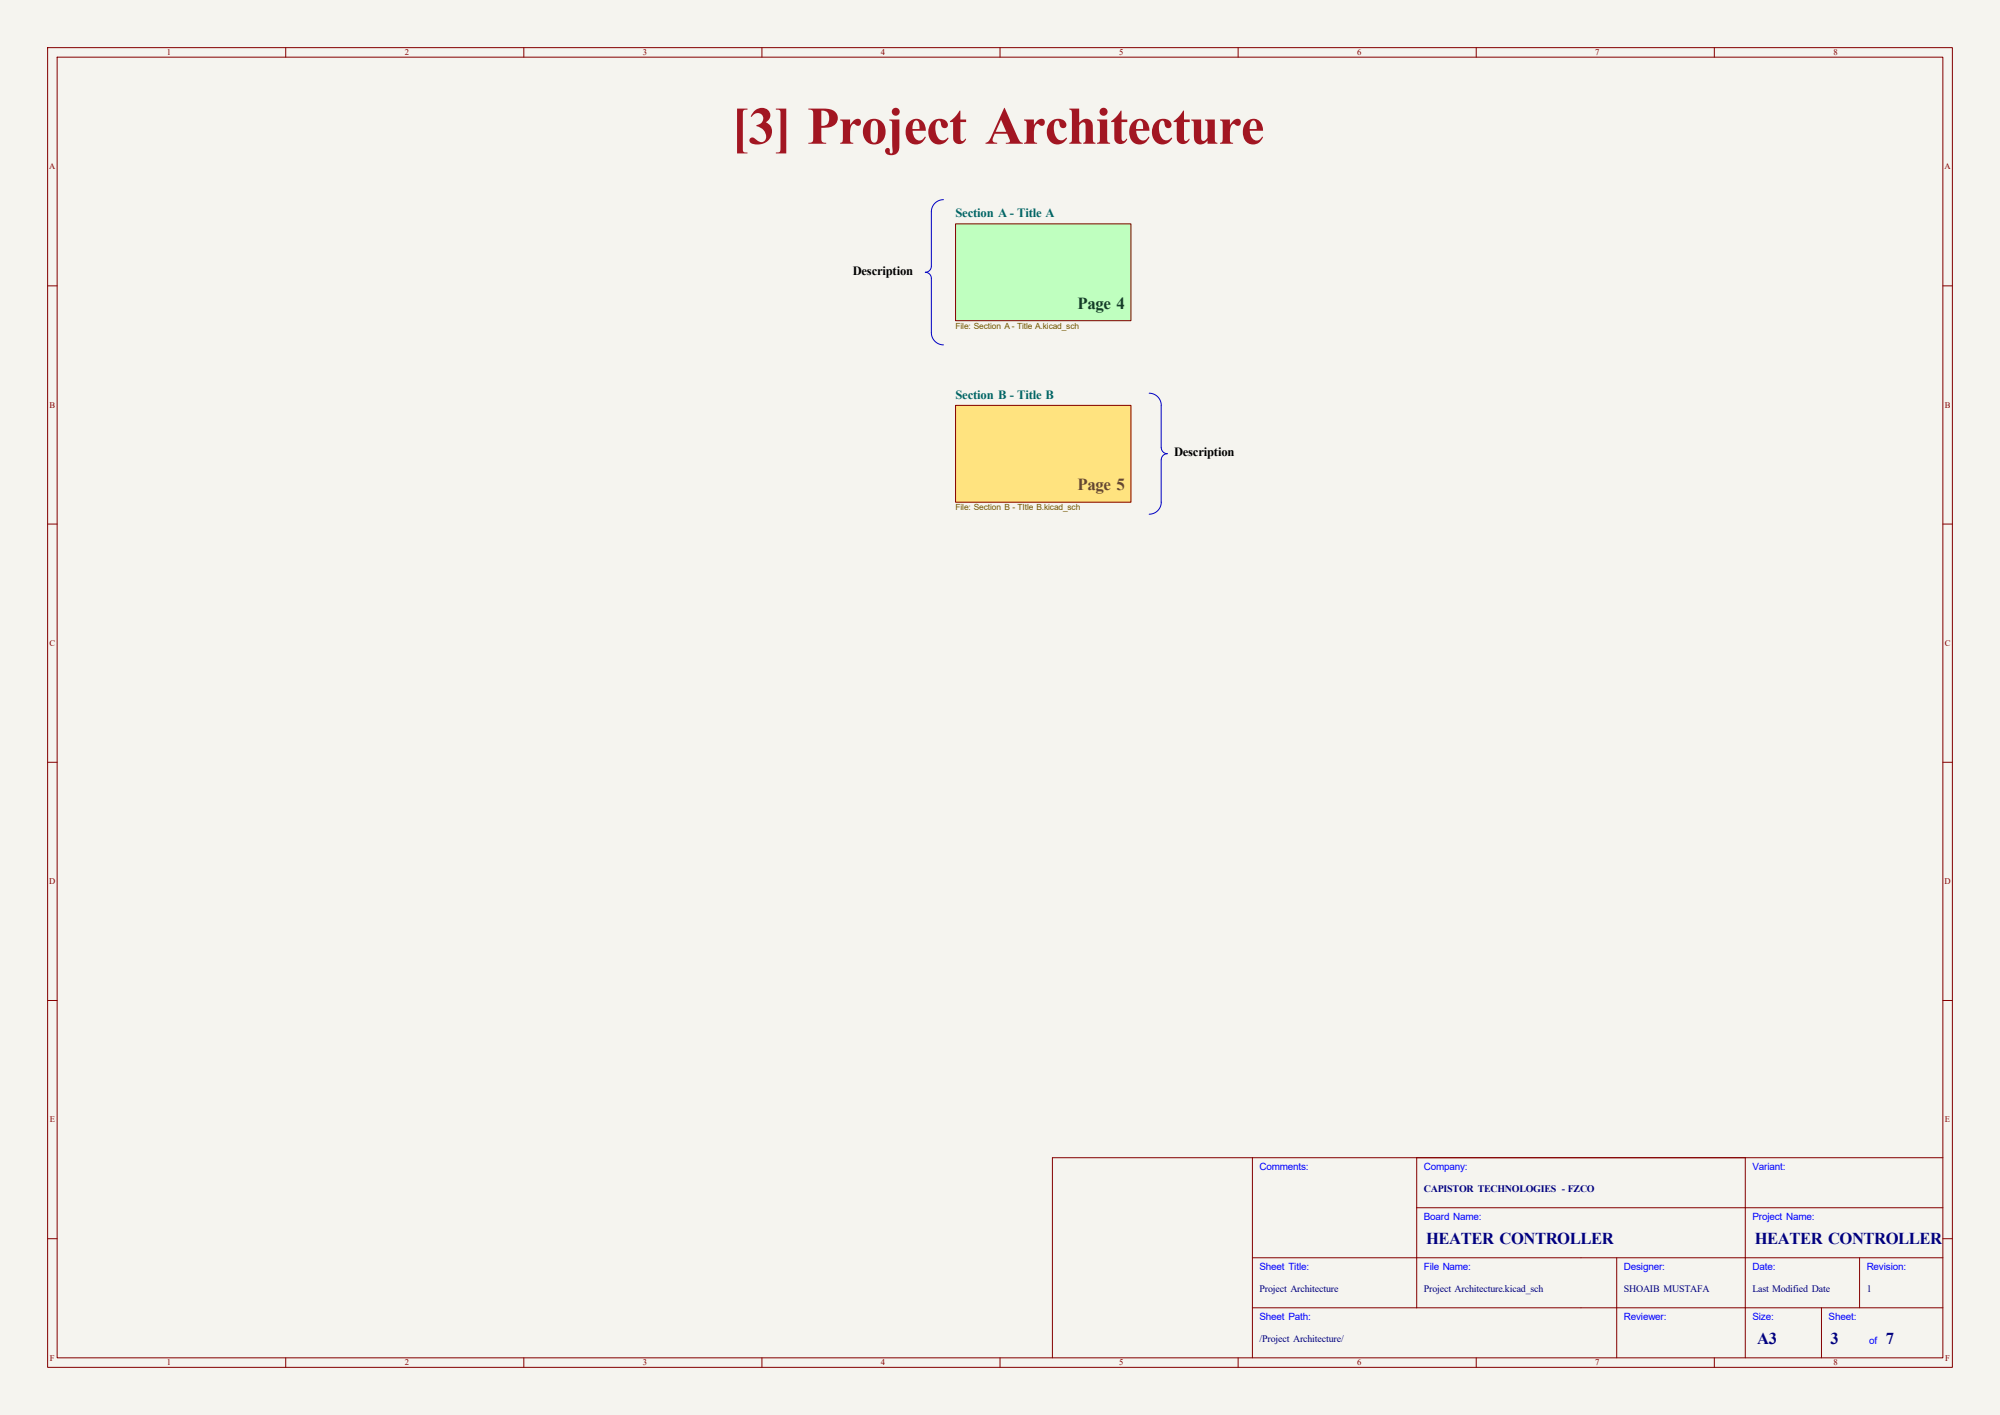
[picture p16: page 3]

/Project Architecture/ Sheet Path: Project Architecture Comments:

Revision: 1 Date: Project Name: Last Modified Date Reviewer: Designer:

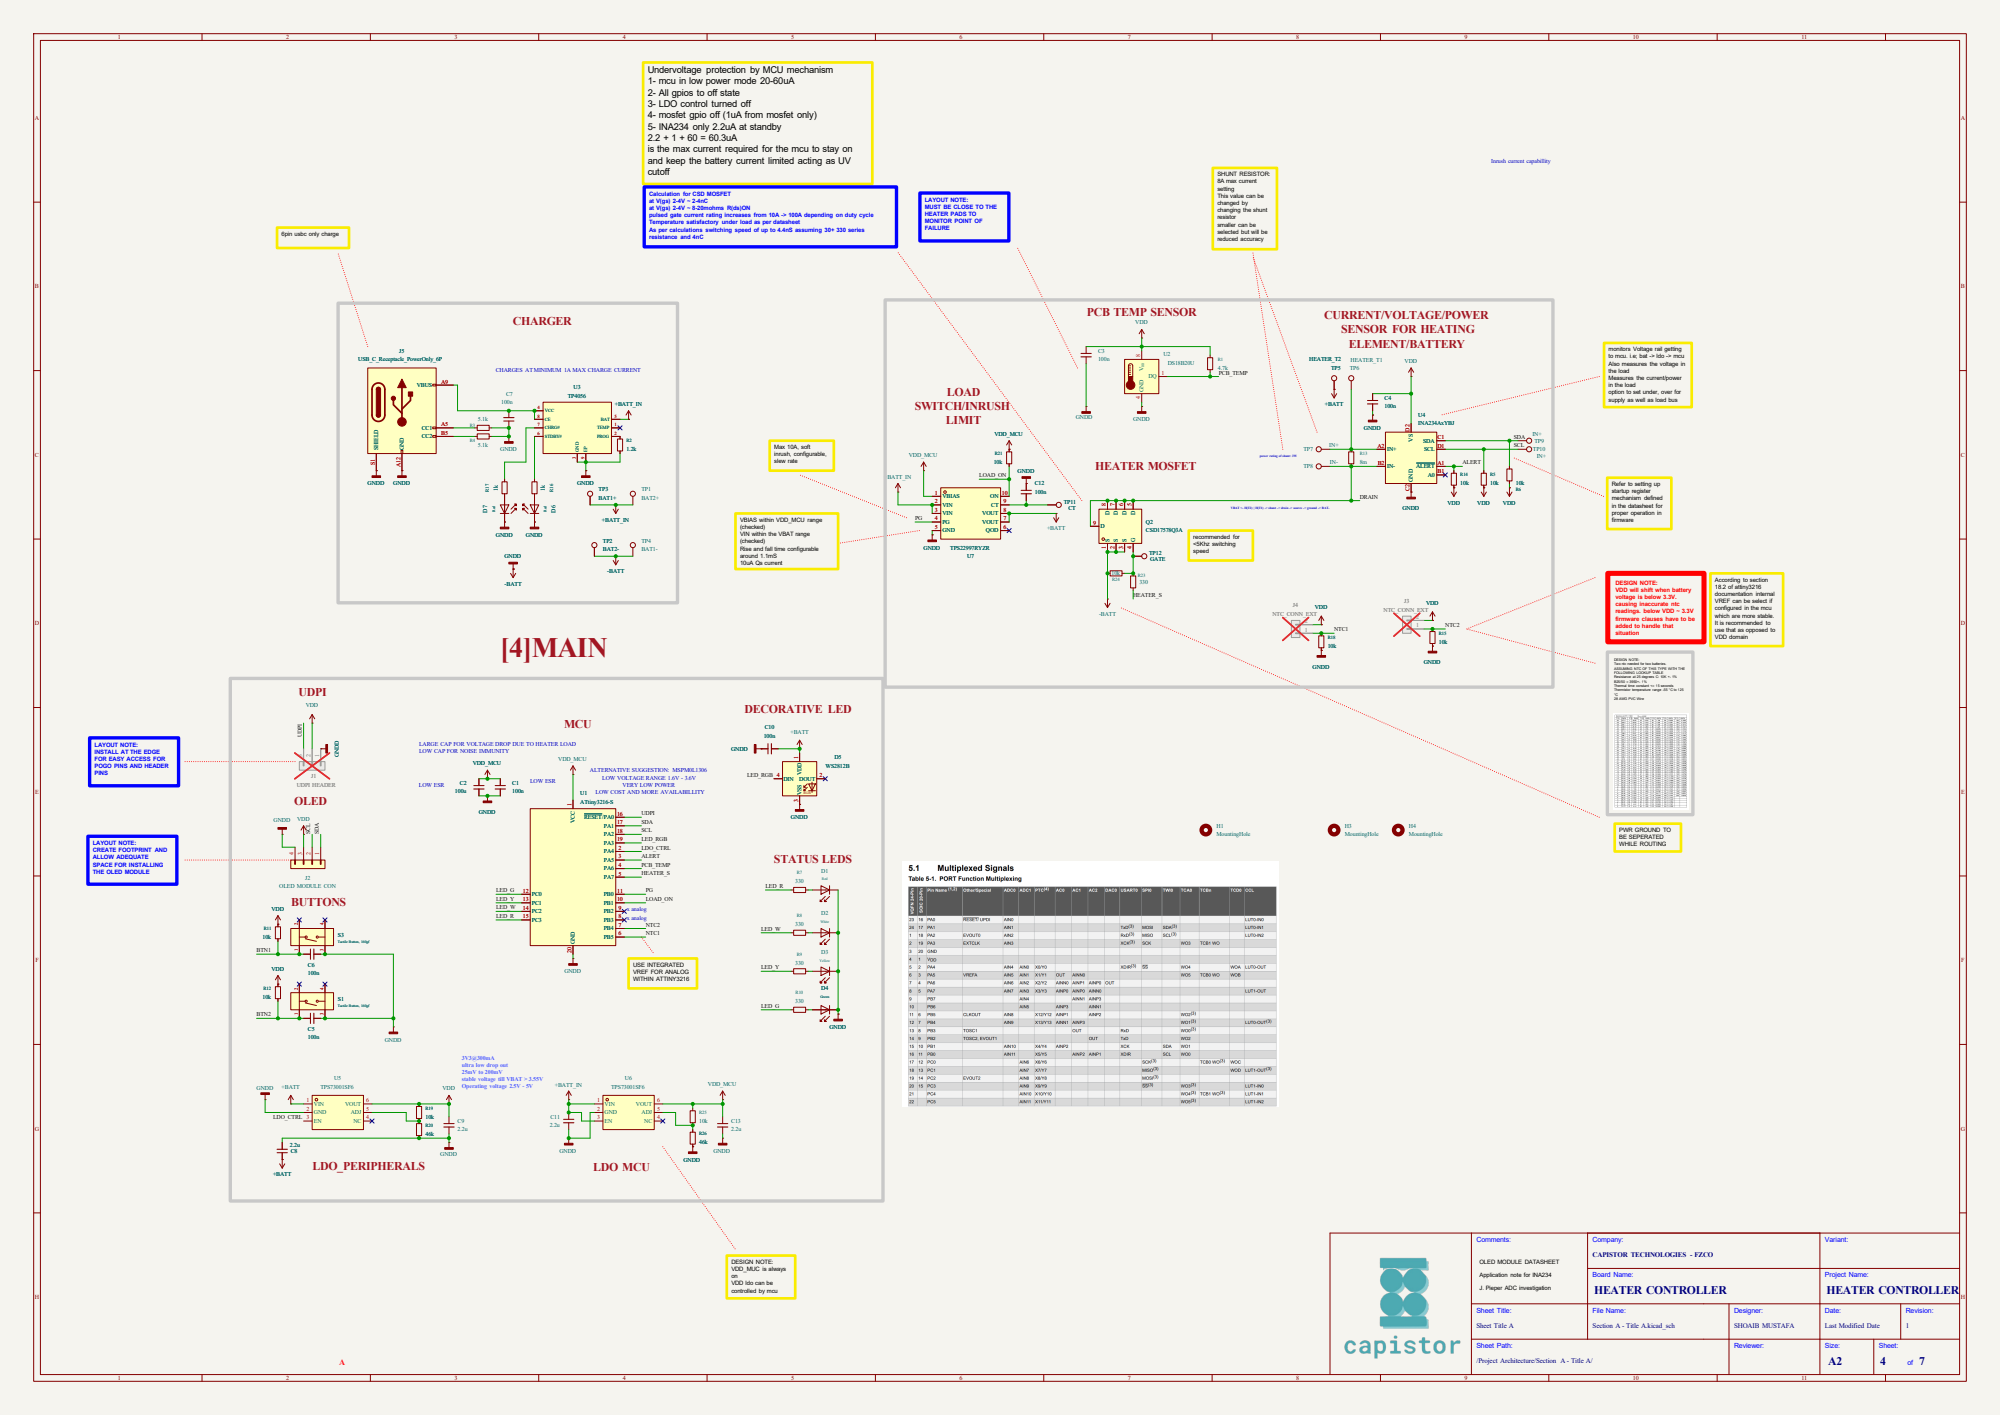
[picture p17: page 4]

inrush, configurable, slew rate Undervoltage protection by MCU mechanism
1- mcu in low power mode 20-60uA
2- All gpios to off state
3- LDO control turned off
4- mosfet gpio off (1uA from mosfet only)
5- INA234 only 2.2uA at standby
is the max current required for the mcu to stay on
and keep the battery current limited acting as UV

SHUNT RESISTOR: 8A max current setting This value can be

Calculation for CSD MOSFET
at V(gs) 2-4V ~ 8-20mohms R(ds)ON
pulsed gate current rating increases from 10A -> 100A depending on duty cycle
Temperature satisfactory under load as per datasheet As per calculations switching speed of up to 4.4nS assuming 30+ 330 series

LAYOUT NOTE: MUST BE CLOSE TO THE HEATER PADS TO MONITOR POINT OF

changed by
changing the shunt resistor smaller can be

selected but will be

use that as opposed to VDD domain PCB TEMP SENSOR

BE SEPERATED WHILE ROUTING CHARGER

to mcu. i.e; bat -> ldo -> mcu Also measures the voltage in

VBAT <- H(T2) | H(T1) -> shunt -> drain -> source -> ground -> BAT- CHARGES AT MINIMUM 1A MAX CHARGE CURRENT

the load Measures the current/power

in the load
option to set under, over for supply as well as load bus

3 VCC 4 BAT 5 STDBY# 6 CHRG# 7 CE 8 EP

power rating of shunt: 3W

Refer to setting up
startup register mechanism defined

in the datasheet for proper operation in

VBIAS within VDD_MCU range
(checked) VIN within the VBAT range

(checked) Rise and fall time configurable

DESIGN NOTE: VDD will shift when battery

According to section
18.2 of attiny3216
documentation internal VREF can be select if configured in the mcu which are more stable.

voltage is below 3.3V. causing inaccurate ntc

readings. below VDD ~ 3.3V
firmware clauses have to be
added to handle that situation

It is recommended to

DESIGN NOTE: Two ntc needed for two batteries. ASSUMING NTC OF THIS TYPE WITH THE

FOLLOWING LOOKUP TABLE Resistance at 25 degrees C: 10K +- 1%

Thermal time constant <= 15 seconds Thermistor temperature range -55 °C to 125

LAYOUT NOTE:
INSTALL AT THE EDGE
FOR EASY ACCESS FOR
POGO PINS AND HEADER
PINS

x analog LARGE CAP FOR VOLTAGE DROP DUE TO HEATER LOAD
LOW CAP FOR NOISE IMMUNITY

LAYOUT NOTE: CREATE FOOTPRINT AND

VREF FOR ANALOG WITHIN ATTINY3216 LDO MCU

ultra low drop out 25mV to 200mV stable voltage till VBAT > 3.55V Operating voltage 2.5V - 5V

/Project Architecture/Section A - Title A/ Sheet Path: Sheet Title A

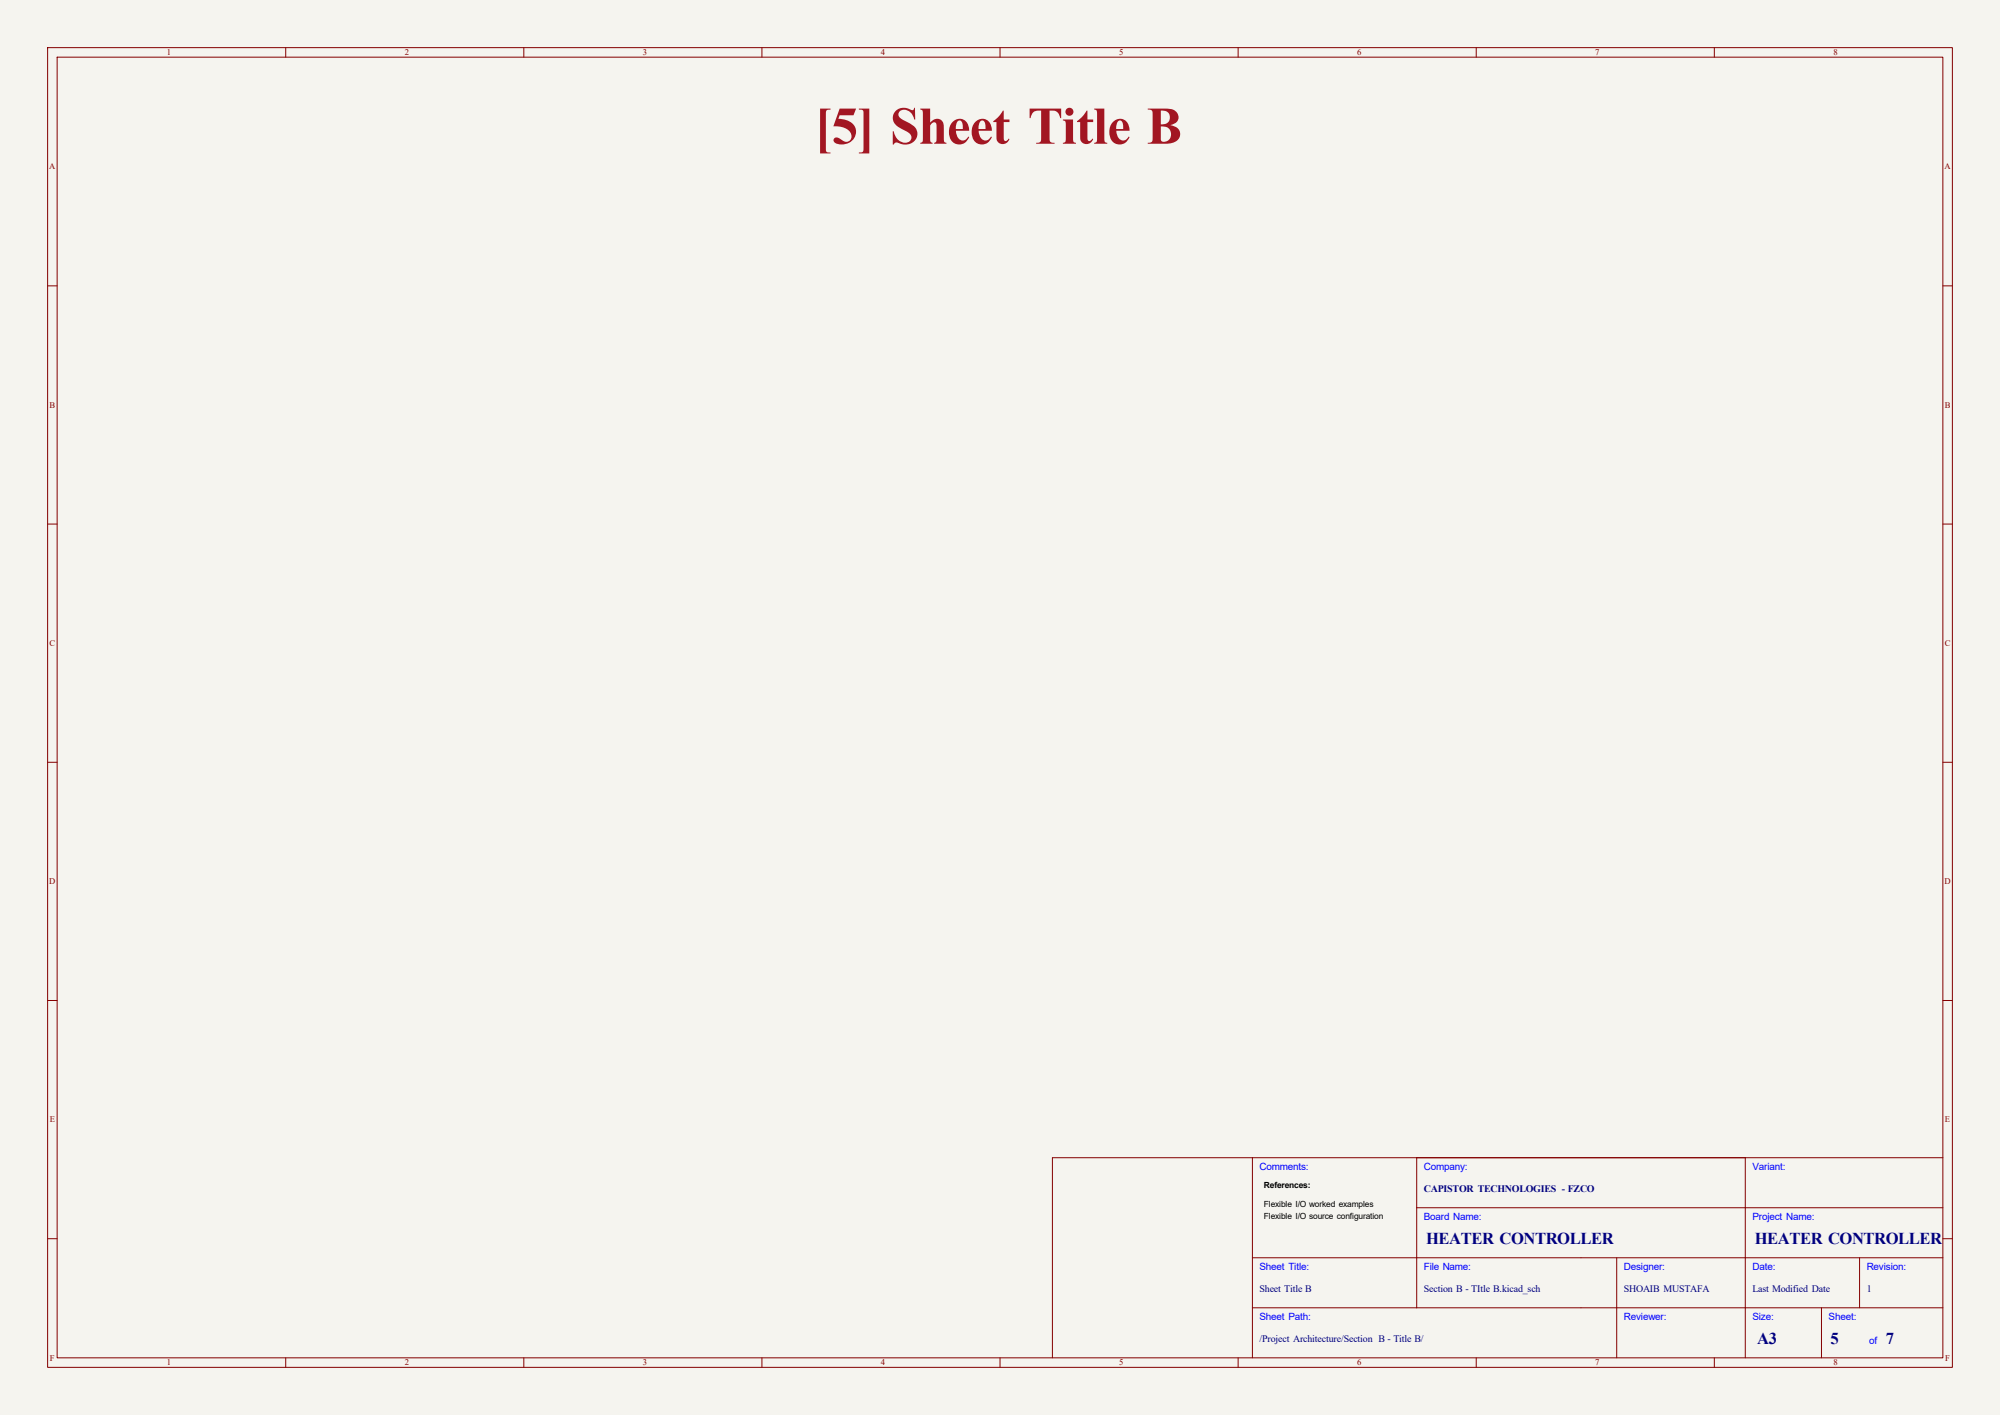
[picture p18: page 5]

/Project Architecture/Section B - Title B/ Sheet Path: Sheet Title B Comments: [5] Sheet Title B

Flexible I/O source configuration (https://jpieper.com/2022/06/28/flexible-i-o-source-configuration/) Flexible I/O worked examples (https://jpieper.com/2022/06/30/flexible-i-o-worked-examples/) References:

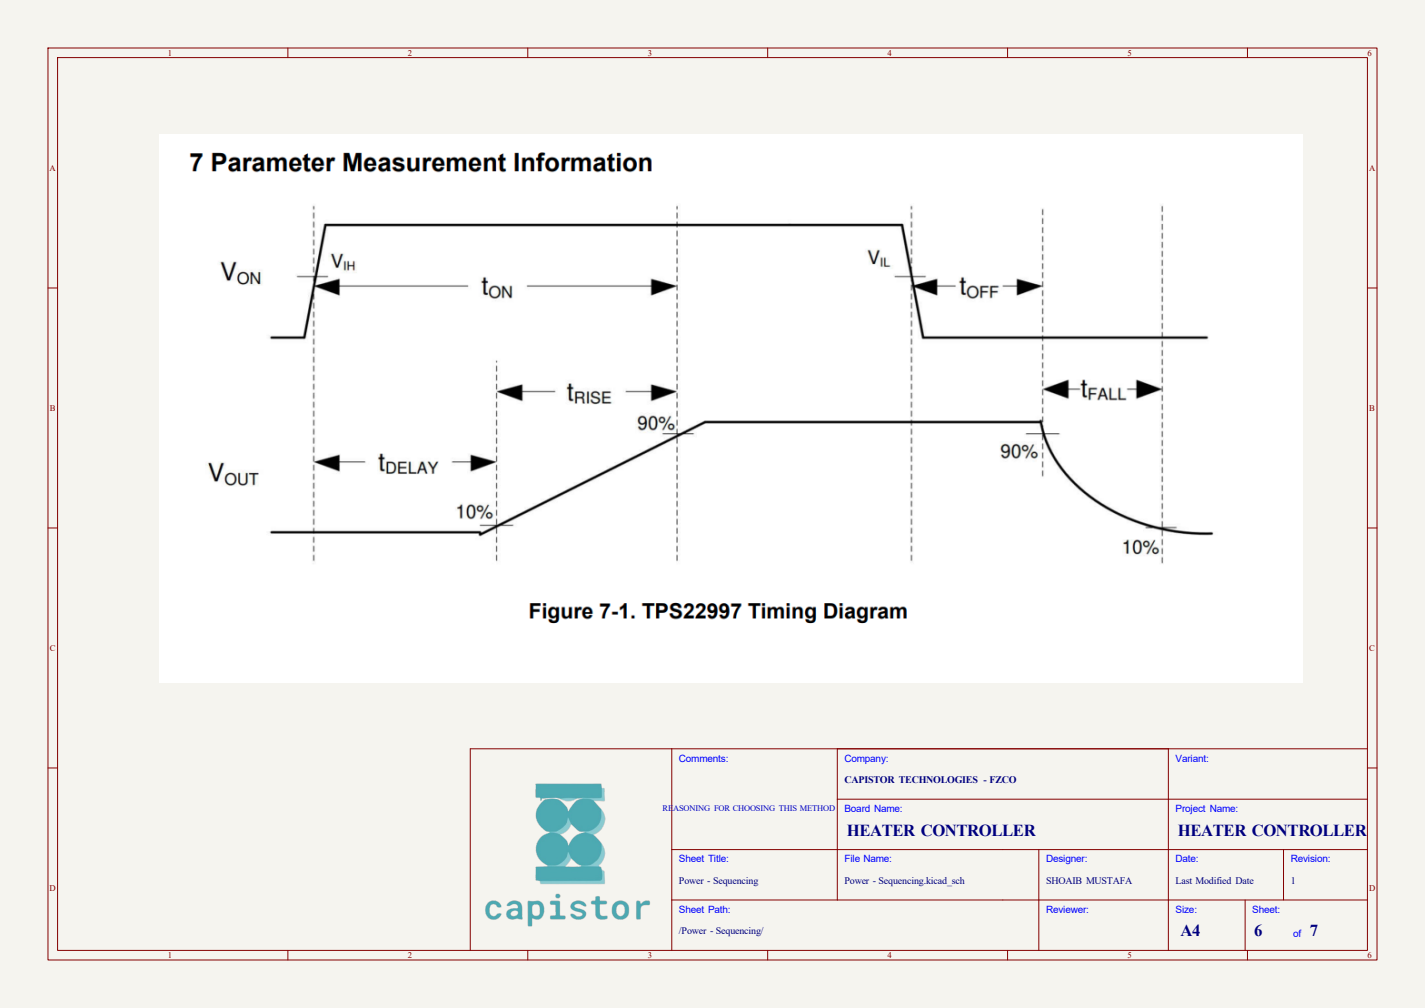
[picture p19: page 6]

/Power - Sequencing/ Sheet Path: Power - Sequencing Comments: REASONING FOR CHOOSING THIS METHOD

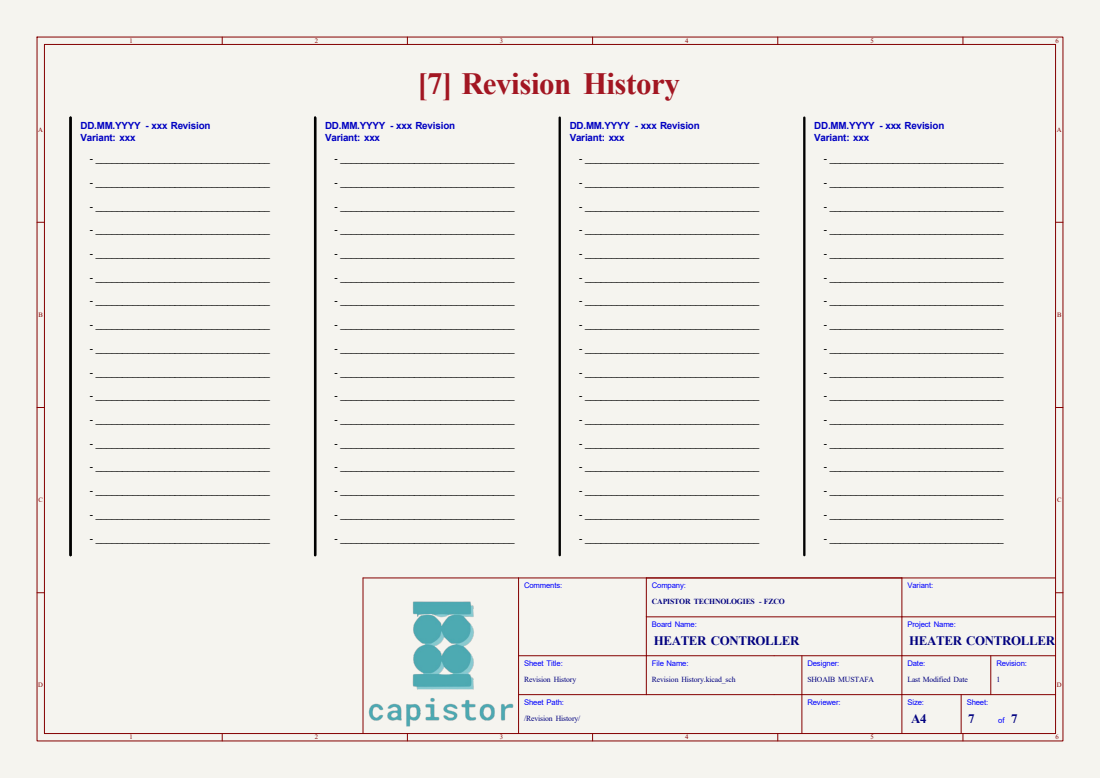
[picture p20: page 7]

- _________________________________ DD.MM.YYYY - xxx Revision
Variant: xxx

Variant: xxx DD.MM.YYYY - xxx Revision

/Revision History/ Sheet Path: Revision History Comments:

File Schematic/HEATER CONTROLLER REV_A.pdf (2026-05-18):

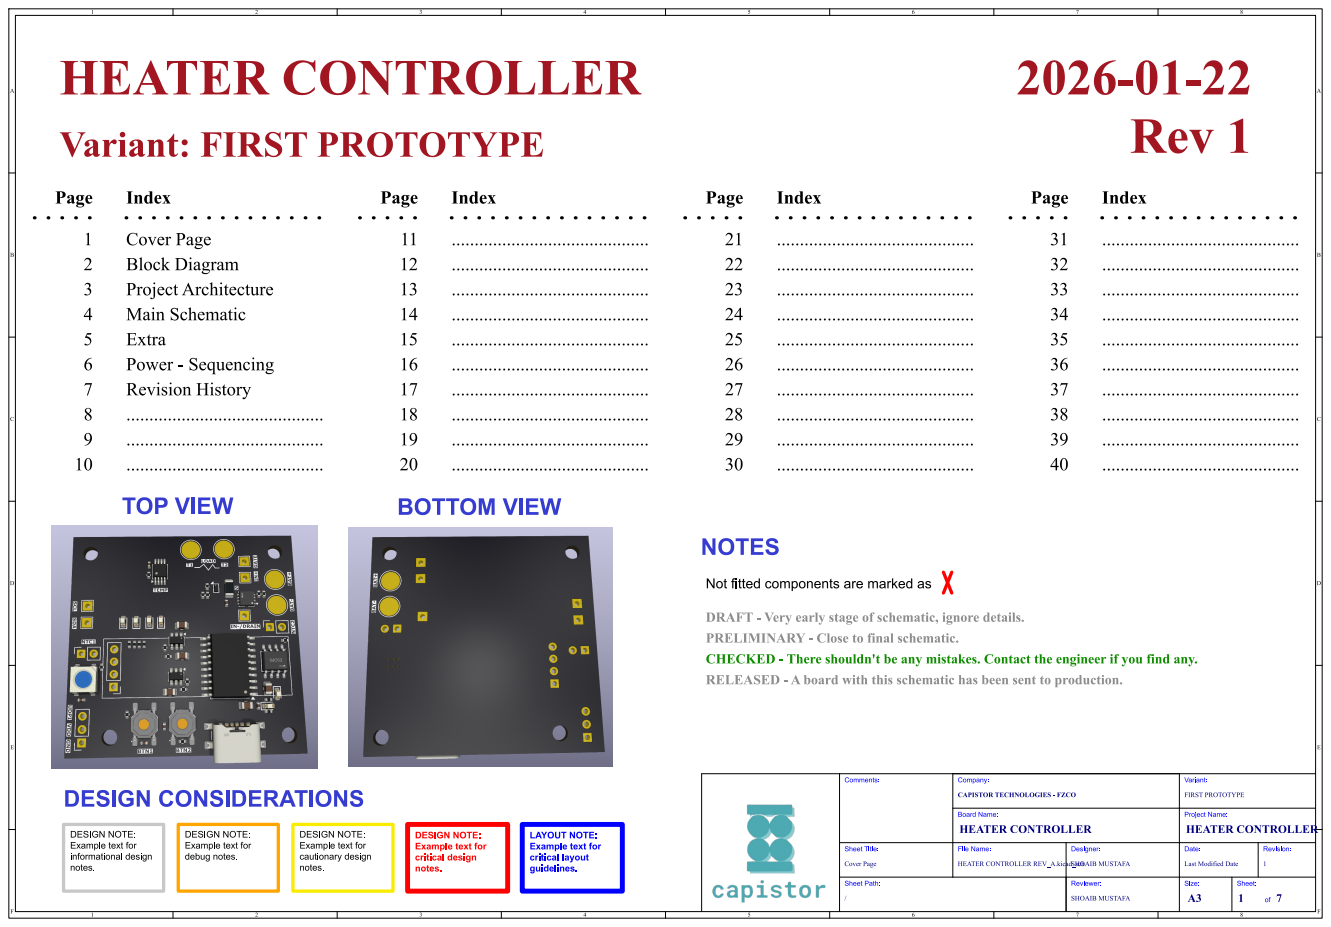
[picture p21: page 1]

Not fitted components are marked as

DRAFT - Veryearlystageof schematic,ignoredetails.

CHECKED - Thereshouldn'tbeanymistakes.Contacttheengineerif youfindany.
RELEASED - A boardwiththisschematichasbeensenttoproduction.

Revision: 1 Date: Project Name: LastModified Date Reviewer: SHOAIB MUSTAFA Designer: HEATERCONTROLLERREV_A.kicad_sch SHOAIB MUSTAFA

File: Project Architecture.kicad_sch DESIGN NOTE:
Example text for
informational design
notes.

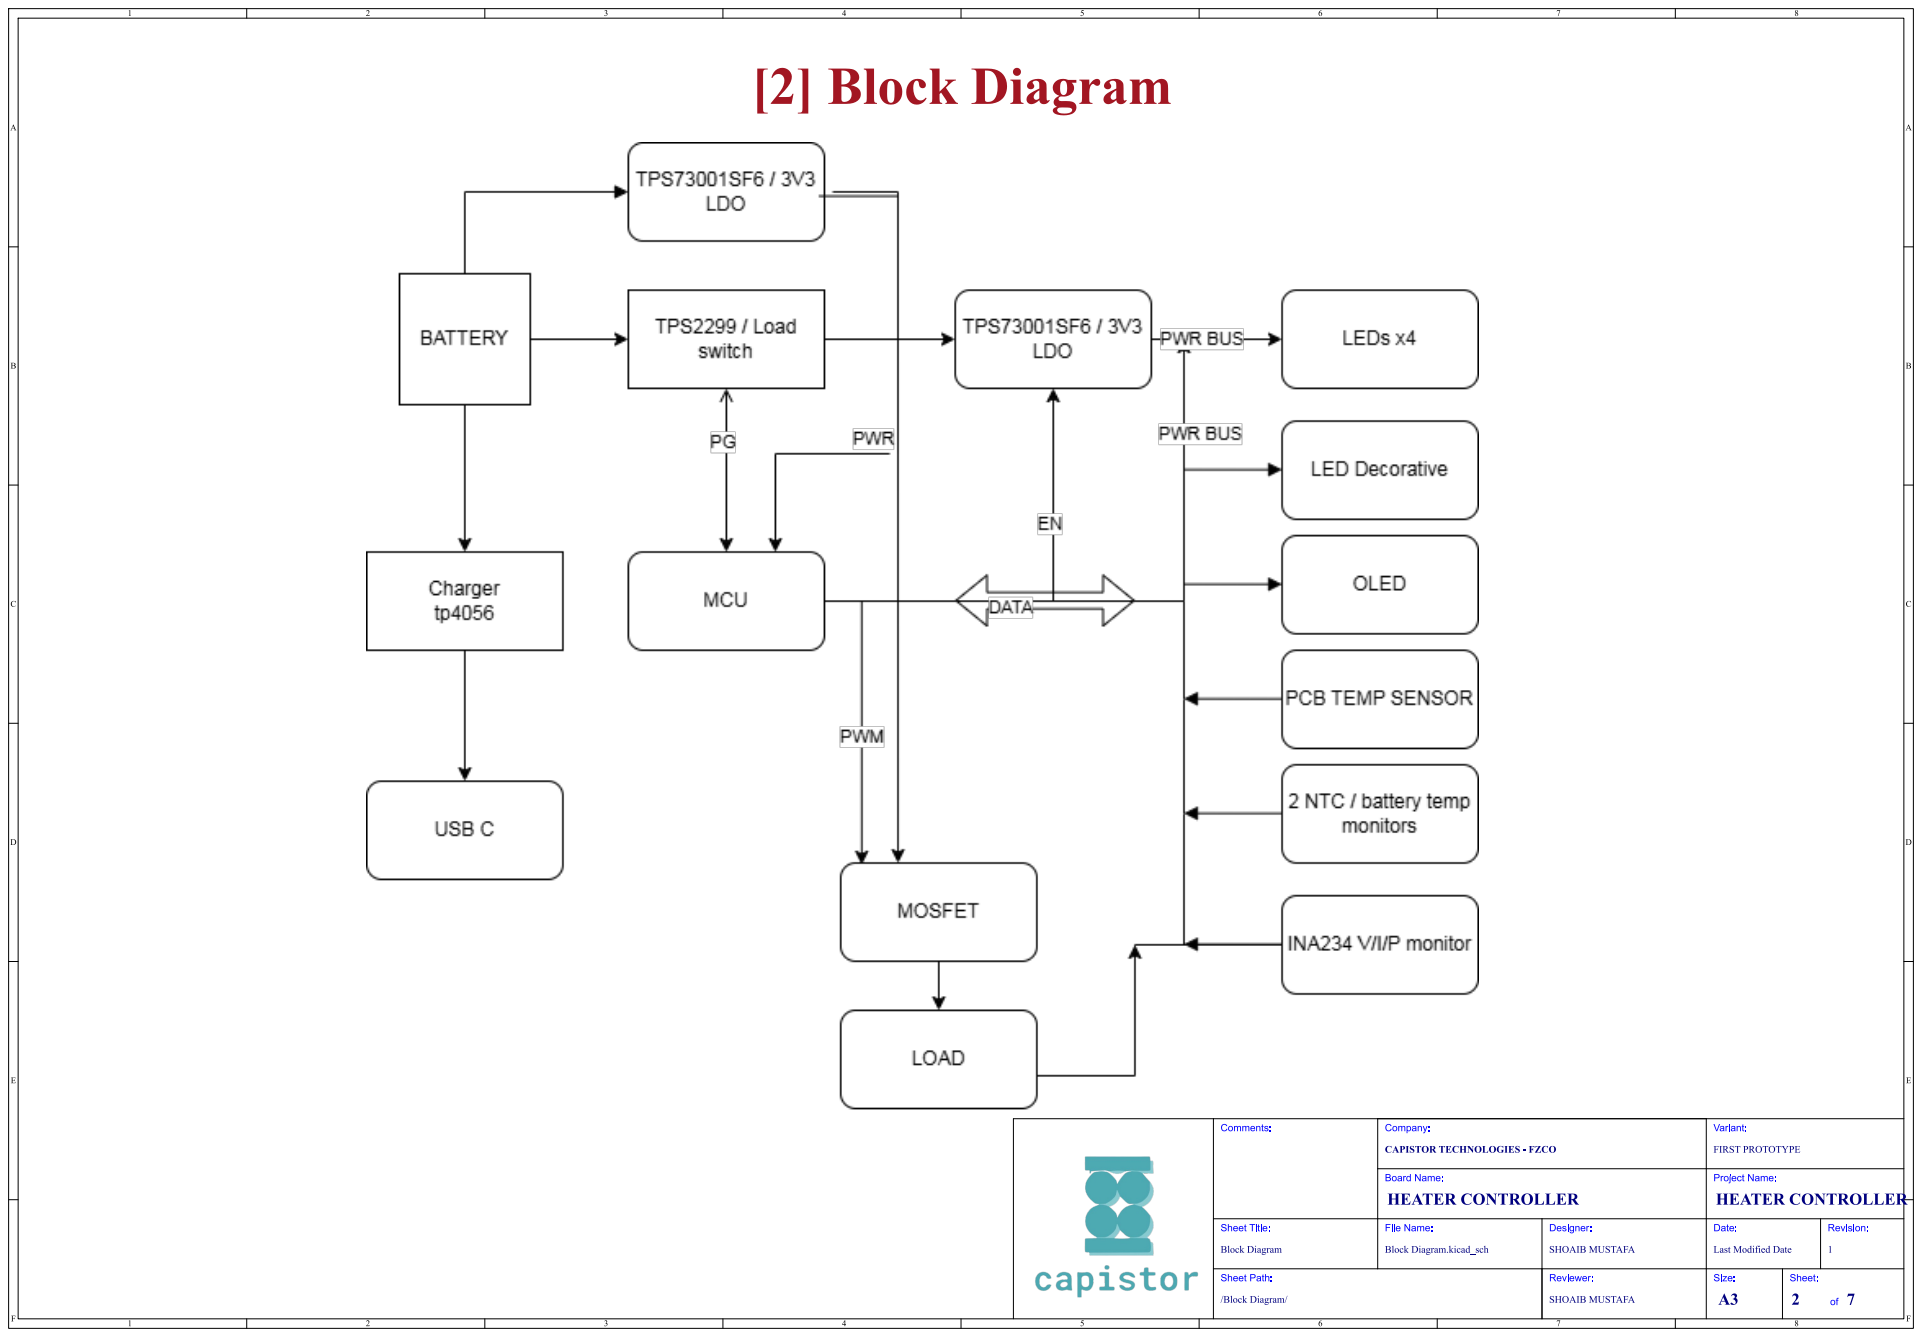
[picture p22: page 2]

/Block Diagram/ Sheet Path: Block Diagram

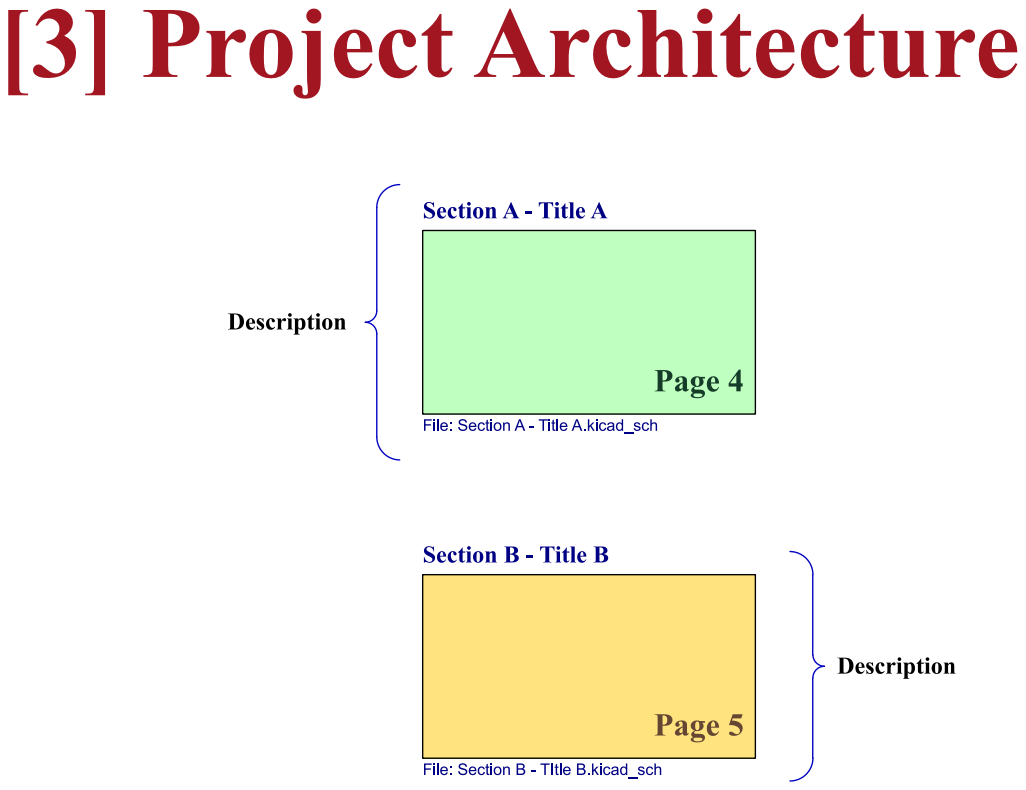
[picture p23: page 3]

[3] ProjectArchitecture
File: Section B - TItle B.kicad_sch SectionA - Title A

/ProjectArchitecture/ Sheet Path: ProjectArchitecture Comments:

Revision: 1 Date: Project Name: LastModified Date Reviewer: SHOAIB MUSTAFA Designer:

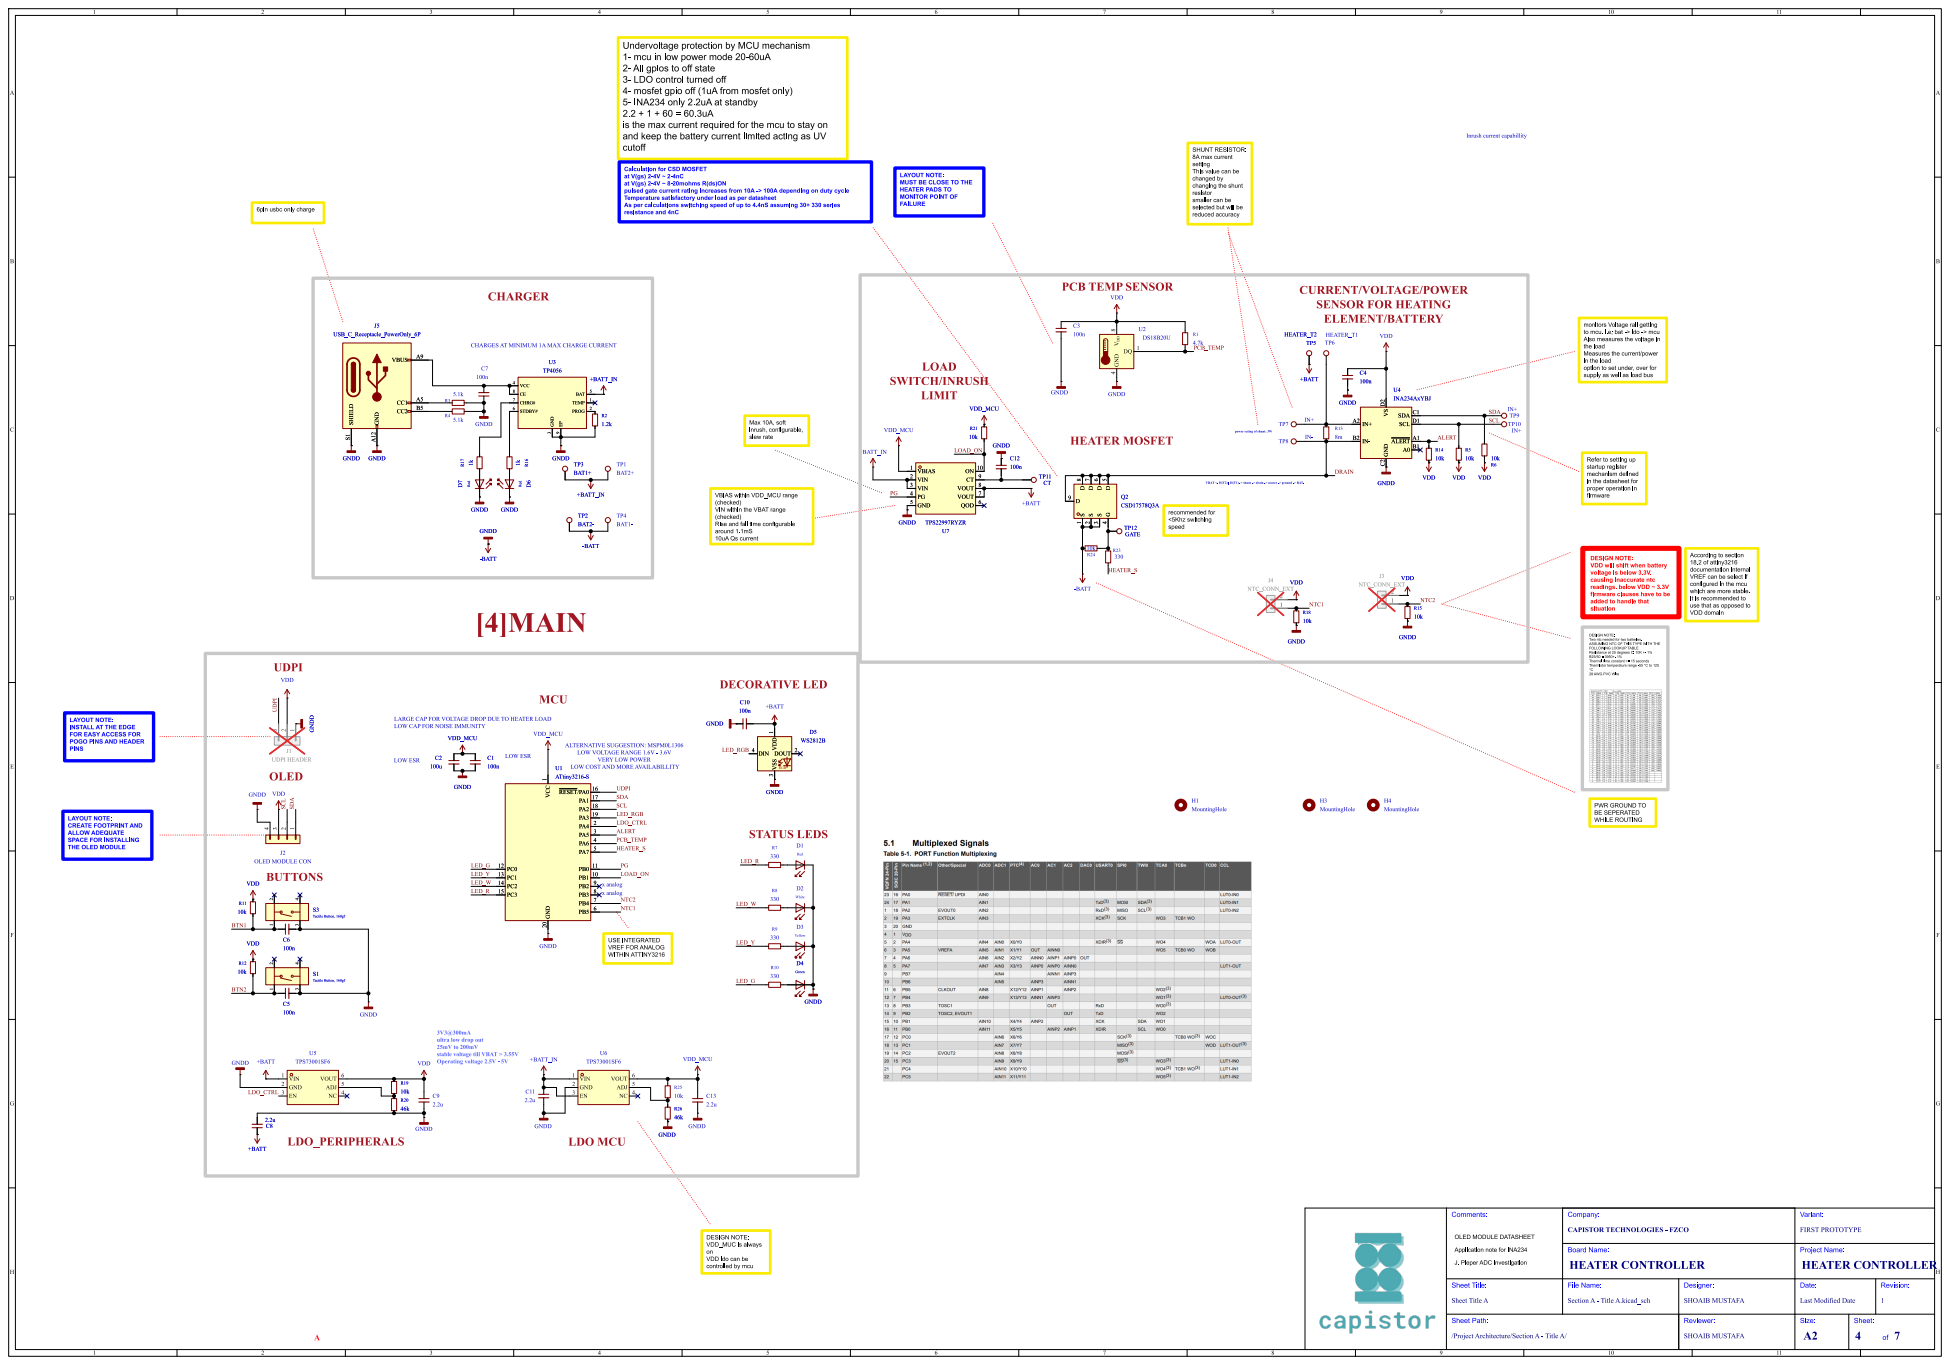
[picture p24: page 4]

inrush, configurable, slew rate Undervoltage protection by MCU mechanism
1- mcu in low power mode 20-60uA
2- All gpios to off state
3- LDO control turned off
4- mosfet gpio off (1uA from mosfet only)
5- INA234 only 2.2uA at standby
is the max current required for the mcu to stay on
and keep the battery current limited acting as UV
cutoff Calculation for CSD MOSFET

SHUNT RESISTOR: 8A max current setting This value can be

at V(gs) 2-4V ~ 8-20mohms R(ds)ON
pulsed gate current rating increases from 10A -> 100A depending on duty cycle
Temperature satisfactory under load as per datasheet As per calculations switching speed of up to 4.4nS assuming 30+ 330 series

LAYOUT NOTE: MUST BE CLOSE TO THE HEATER PADS TO MONITOR POINT OF

changed by
changing the shunt resistor smaller can be

selected but will be

reduced accuracy VBIAS within VDD_MCU range

monitors Voltage rail getting
to mcu. i.e; bat -> ldo -> mcu Also measures the voltage in

CHARGESAT MINIMUM 1A MAX CHARGECURRENT

the load Measures the current/power

in the load
option to set under, over for supply as well as load bus

use that as opposed to VDD domain Max 10A, soft

firmware PWR GROUND TO

startup register mechanism defined

VBAT <- H(T2) | H(T1) -> shunt-> drain-> source-> ground-> BAT-

in the datasheet for proper operation in

(checked) VIN within the VBAT range

(checked) Rise and fall time configurable

around 1.1mS
10uA Qs current DECORATIVE LED

DESIGN NOTE: VDD will shift when battery

According to section
18.2 of attiny3216
documentation internal VREF can be select if configured in the mcu which are more stable.

voltage is below 3.3V. causing inaccurate ntc

readings. below VDD ~ 3.3V
firmware clauses have to be
added to handle that situation

It is recommended to

DESIGN NOTE: Two ntc needed for two batteries. ASSUMING NTC OF THIS TYPE WITH THE

FOLLOWING LOOKUP TABLE Resistance at 25 degrees C: 10K +- 1%

Thermal time constant <= 15 seconds Thermistor temperature range -55 þÿ°Cto 125

LAYOUT NOTE:
INSTALL AT THE EDGE
FOR EASY ACCESS FOR
POGO PINS AND HEADER

LARGE CAPFORVOLTAGEDROPDUE TO HEATERLOAD

BE SEPERATED WHILE ROUTING

LAYOUT NOTE: CREATE FOOTPRINT AND

VREF FOR ANALOG WITHIN ATTINY3216 LDO MCU

DESIGN NOTE: VDD_MUC is always onVDD ldo can be

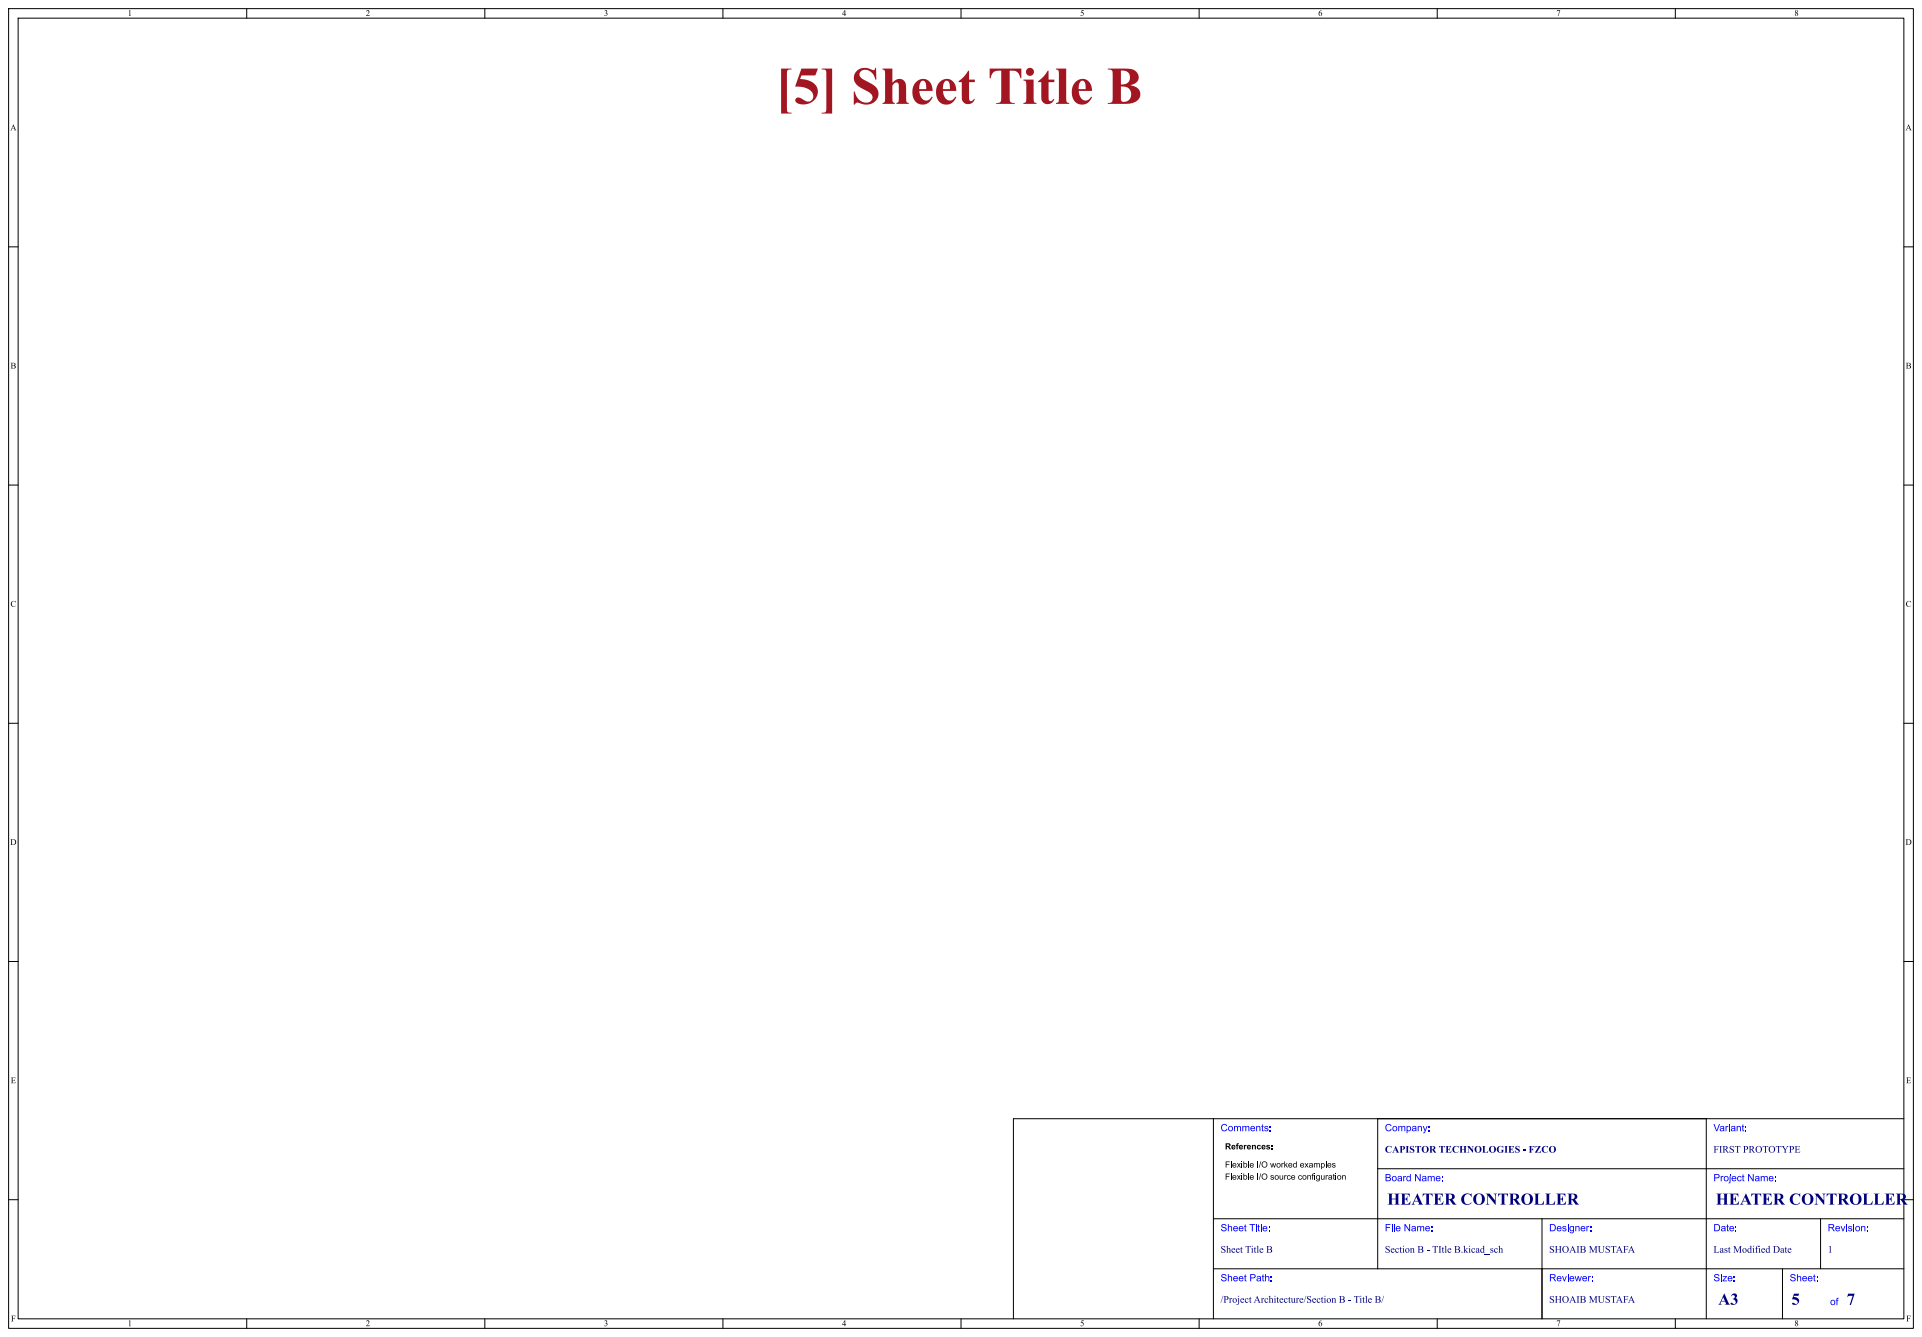
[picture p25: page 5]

/ProjectArchitecture/SectionB - Title B/ Sheet Path: SheetTitle B Comments: [5] SheetTitle B

Flexible I/O source configuration (https://jpieper.com/2022/06/28/flexible-i-o-source-configuration/) Flexible I/O worked examples (https://jpieper.com/2022/06/30/flexible-i-o-worked-examples/) References:


/Power- Sequencing/ Sheet Path: Power- Sequencing Comments: REASONINGFORCHOOSINGTHIS METHOD


- _________________________________ DD.MM.YYYY - xxx Revision
Variant: xxx

Variant: xxx DD.MM.YYYY - xxx Revision

/RevisionHistory/ Sheet Path: RevisionHistory Comments:

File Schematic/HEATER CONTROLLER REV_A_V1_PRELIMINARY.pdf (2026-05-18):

# Page

# Index

Sheet: of 7; Size: A3; Board Name:; Variant: FIRSTPROTOTYPE Company: CAPISTOR TECHNOLOGIES - FZCO HEATER CONTROLLER; HEATER CONTROLLER; Sheet Title:; File Name:; /Sheet Path: CoverPage Comments:; RevisionHistory; NOTES; Block Diagram; CoverPage; Main Schematic; ProjectArchitecture; Index; Page; ........................................... Page; Rev1; ........................................... DRAFT - Veryearlystageof schematic,ignoredetails.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

HEATER CONTROLLER
Variant:FIRST PROTOTYPE

Not fitted components are marked as

PRELIMINARY - Closetofinal schematic.
CHECKED - Thereshouldn'tbeanymistakes.Contacttheengineerif youfindany.
RELEASED - A boardwiththisschematichasbeensenttoproduction.

Revision: 1 Date: Project Name: LastModified Date Reviewer: SHOAIB MUSTAFA Designer: HEATERCONTROLLERREV_A.kicad_sch SHOAIB MUSTAFA

DESIGN NOTE:
Example text for
informational design
notes.

File: Project Architecture.kicad_sch DESIGN NOTE:
debug notes.

cautionary design

critical design

LAYOUT NOTE:
critical layout
guidelines.

1 | 2 | 3 | 4 | 5 | 6 | 7 | 8 | 9 | 10 | 11
1 | 2 | 3 | 4 | 5 | 6 | 7 | 8 | 9 | 10 | 11

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
Sheet: of 7
Size: A2
Revision: 1 Date: Project Name: LastModified Date Reviewer: SHOAIB MUSTAFA Designer: SectionA - Title A.kicad_sch | SHOAIB MUSTAFA
Board Name: | Variant: FIRSTPROTOTYPE Company: CAPISTOR TECHNOLOGIES - FZCO HEATER CONTROLLER | HEATER CONTROLLER
Sheet Title: | File Name:

/ProjectArchitecture/SectionA - Title A/ Sheet Path: SheetTitle A Comments:

H4 MountingHole H1 MountingHole

VDD

H2 MountingHole | H3 MountingHole
+BATT | S

1 S

2 S

3 G

4 D

9 D 8 D 7 D

6 D

5 Q2 CSD17578Q3A

1

2

J4 NTC_CONN_EXTGNDD
-BATT

R3 5.1k C7

# 100u GNDD

4

3

2

1

J2 OLED MODULE CON

VCC

4 CE
8 CHRG#
7 STDBY#
6 | GND

3 EP

9 BAT

5 TEMP
1 PROG

2 U3 TP4056 R4 5.1k

C11

2.2u | GNDD

VDD

3

2

1

J1 UDPI HEADER GNDD

TP9

IN+

R8 1kR7 1k | D1
Red +BATT | VDD

R6 10k VDD GNDD

VDD

R5 10k

R11 10kVDD

TP6 HEATER_T1 VDD

TP5 HEATER_T2 +BATT

1

2

J3 NTC_CONN_EXT

R9 1k

VDD

# R15 10k GNDD

D3

Yellow

C4
100n | R14 10k D2 White VDD_MCU

R13 10m

IN+ A2

IN- B2 | VS D² GND C² | SDA C1 SCL D1 ~{ALERT} A1 A0 B1 U4
INA234AxYBJ R18 10k VDD GNDD GNDD GNDD

C6

100u | C2

100u VDD

C8

2.2u +BATT

1

3

2

4 S1

TactileButton,160gf | GNDD

C9

2.2u +BATT

1

3

2

4 S3

TactileButton,160gf | GNDD

R26 45k

R1 4.7k

VDD

R12 10k

IN 1 EN 3 NR 4 | GND

2 OUT 5 ADJ 2 U5 TPS73001SF6

TP8

IN- TP7

IN+

GNDD

C5
100u | GNDD

GNDD

C3
100n

## R20 45k R19 10k

# GNDDV_{DD} 8 GND

4 DQ 1U2DS18B20U

VDD

# PC0 12 PC1 13 PC2 14 PC3 15 VCC

## 1 GND 20

~{RESET}/PA016 PA1 17 PA2 18 PA3 19 PA4 2 PA5 3 PA6 4 PA7 5 PB0 11 PB1 10 PB2 9 PB3 8 PB4 7 PB5 6 U1ATtiny3216-S C1
100n | C13

2.2u

VDD_MCU

VDD_MCU GNDD

C10
100n

R25 10k

TP10
IN+
IN 1 EN 3 NR 4 | GND

2 OUT 5 ADJ 2 U6 TPS73001SF6

GNDD

R10 1k D4

Green +BATT

TP2 BAT2-

GNDD

TP4 BAT1-

-BATT GNDD | GNDD | GNDD R¹⁷ 1k | 1k R¹⁶ Red | D⁶

R23 330TP12 GATE

R24 10k D⁷Red

RGB DIN 4 | VDD

## 1 VSS

3 DOUT 2 D5 WS2812B GNDD

+BATT

TP1 BAT2+ TP3 BAT1+ GNDD GNDD

R2 1.2k SHIELD S¹ | GND A¹² | VBUS A9 CC1 A5 CC2 B5
J5 USB_C_Receptacle_PowerOnly_6P | HEATER_S SCL SDA

BTN1

DRAIN

# LDO_CTRL BTN2

PCB_TEMP

NTC1 UDPI | PCB_TEMP

LED_RGB

LED_Y

LED_G

NTC2

LED_R
LED_W
LED_Y

SDA
ALERT | SCL

LED_G

LDO_CTRL | NTC1

LED_RGB

SCL ALERT HEATER_S

LED_R

LED_W

SDA UDPI | NTC2 PCB TEMP SENSOR

# [4]MAIN

# CURRENT/VOLTAGE/POWER SENSORFOR HEATING ELEMENT/BATTERY

SHUNT RESISTOR: 8A max current setting This value can be

changed by
changing the shunt resistor smaller can be

selected but will be

reduced accuracy LAYOUT NOTE: MUST BE CLOSE TO THE HEATER PADS TO MONITOR POINT OF

FAILURE | DESIGN NOTE: VDD will shift when battery

voltage is below 3.3V. causing inaccurate ntc

readings. below VDD ~ 3.3V firmware clauses have to be added to handle that situation

DESIGN NOTE: Two ntc needed for two batteries. ASSUMING NTC OF THIS TYPE WITH THE

FOLLOWING LOOKUP TABLE Resistance at 25 degrees C: 10K +- 1%

B25/50 = 3950+- 1%
Thermal time constant <= 15 seconds Thermistor temperature range -55 þÿ°Cto 125

þÿ°C
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

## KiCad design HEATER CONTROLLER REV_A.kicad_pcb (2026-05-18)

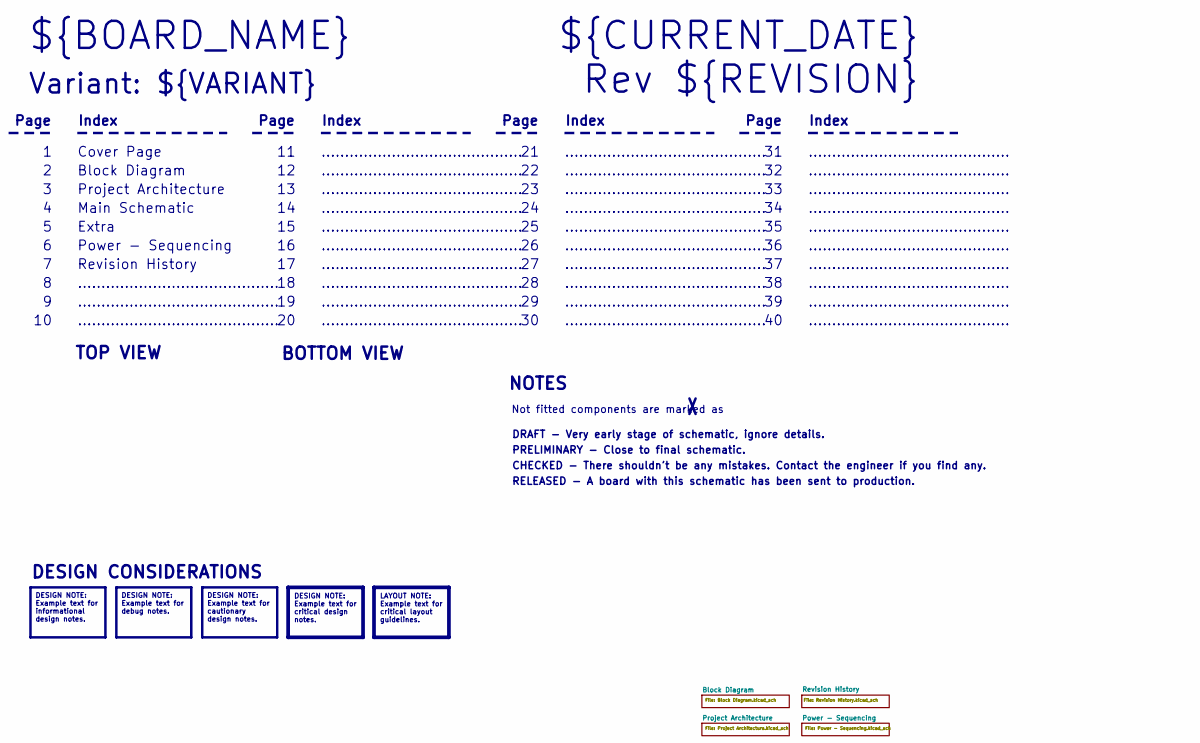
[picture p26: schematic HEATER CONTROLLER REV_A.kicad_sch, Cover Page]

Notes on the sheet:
BOTTOM VIEW
...........................................
RELEASED - A board with this schematic has been sent to production.
Page
TOP VIEW
Not fitted components are marked as
Index
PRELIMINARY - Close to final schematic.
Main Schematic
${CURRENT_DATE}
Variant: ${VARIANT}
Rev ${REVISION}
Extra
${BOARD_NAME}
DRAFT - Very early stage of schematic, ignore details.
Power - Sequencing
Block Diagram
Cover Page
NOTES
Project Architecture
CHECKED - There shouldn't be any mistakes. Contact the engineer if you find any.
DESIGN CONSIDERATIONS
Revision History
DESIGN NOTE: Example text for informational design notes.
LAYOUT NOTE: Example text for critical layout guidelines.
DESIGN NOTE: Example text for cautionary design notes.
DESIGN NOTE: Example text for debug notes.
DESIGN NOTE: Example text for critical design notes.

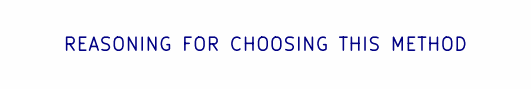
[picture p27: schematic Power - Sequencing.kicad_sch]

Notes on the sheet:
REASONING FOR CHOOSING THIS METHOD

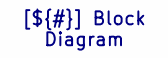
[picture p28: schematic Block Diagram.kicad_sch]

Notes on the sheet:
[${#}] ${TITLE}

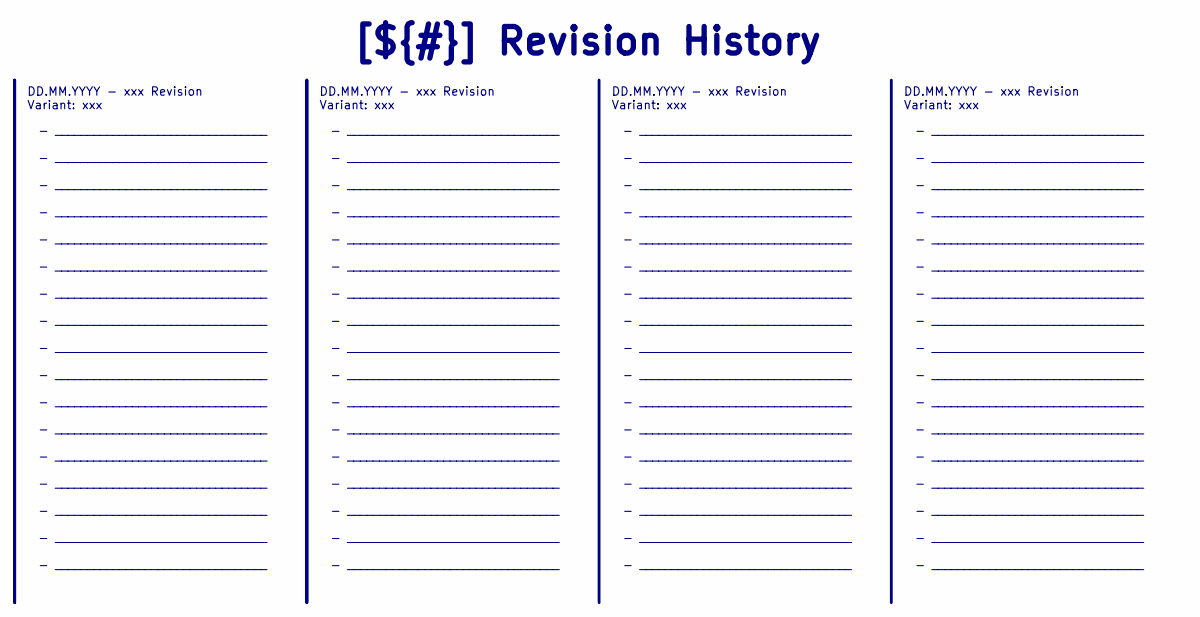
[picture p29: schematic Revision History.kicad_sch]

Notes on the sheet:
- _________________________________ - _________________________________ - _________________________________ - _________________________________ - _________________________________ - _________________________________ - _________________________________ - _________________________________ - _________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
DD.MM.YYYY - xxx Revision Variant: xxx
[${#}] ${TITLE}

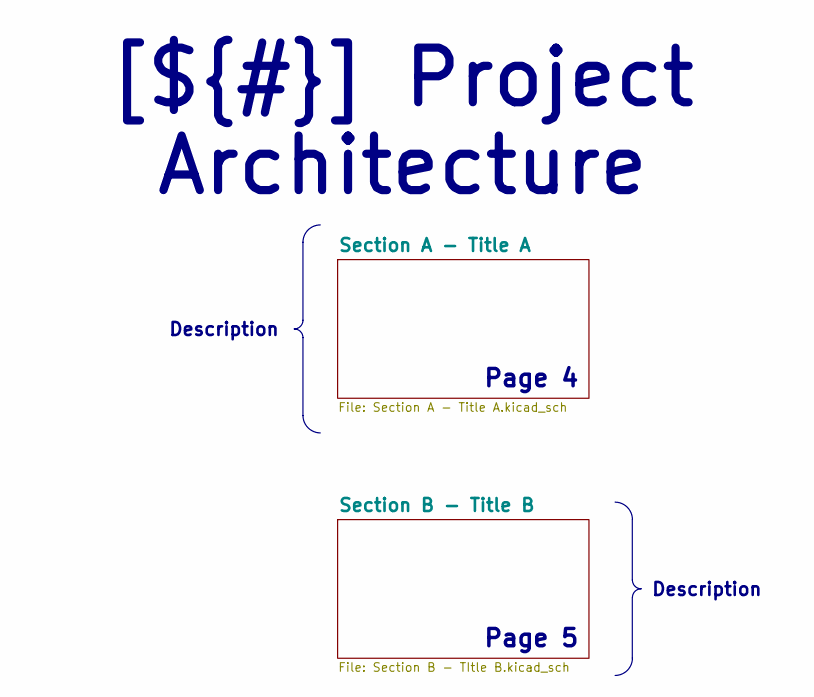
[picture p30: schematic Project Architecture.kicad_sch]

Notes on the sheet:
Page 4
Page 5
Description
[${#}] ${TITLE}

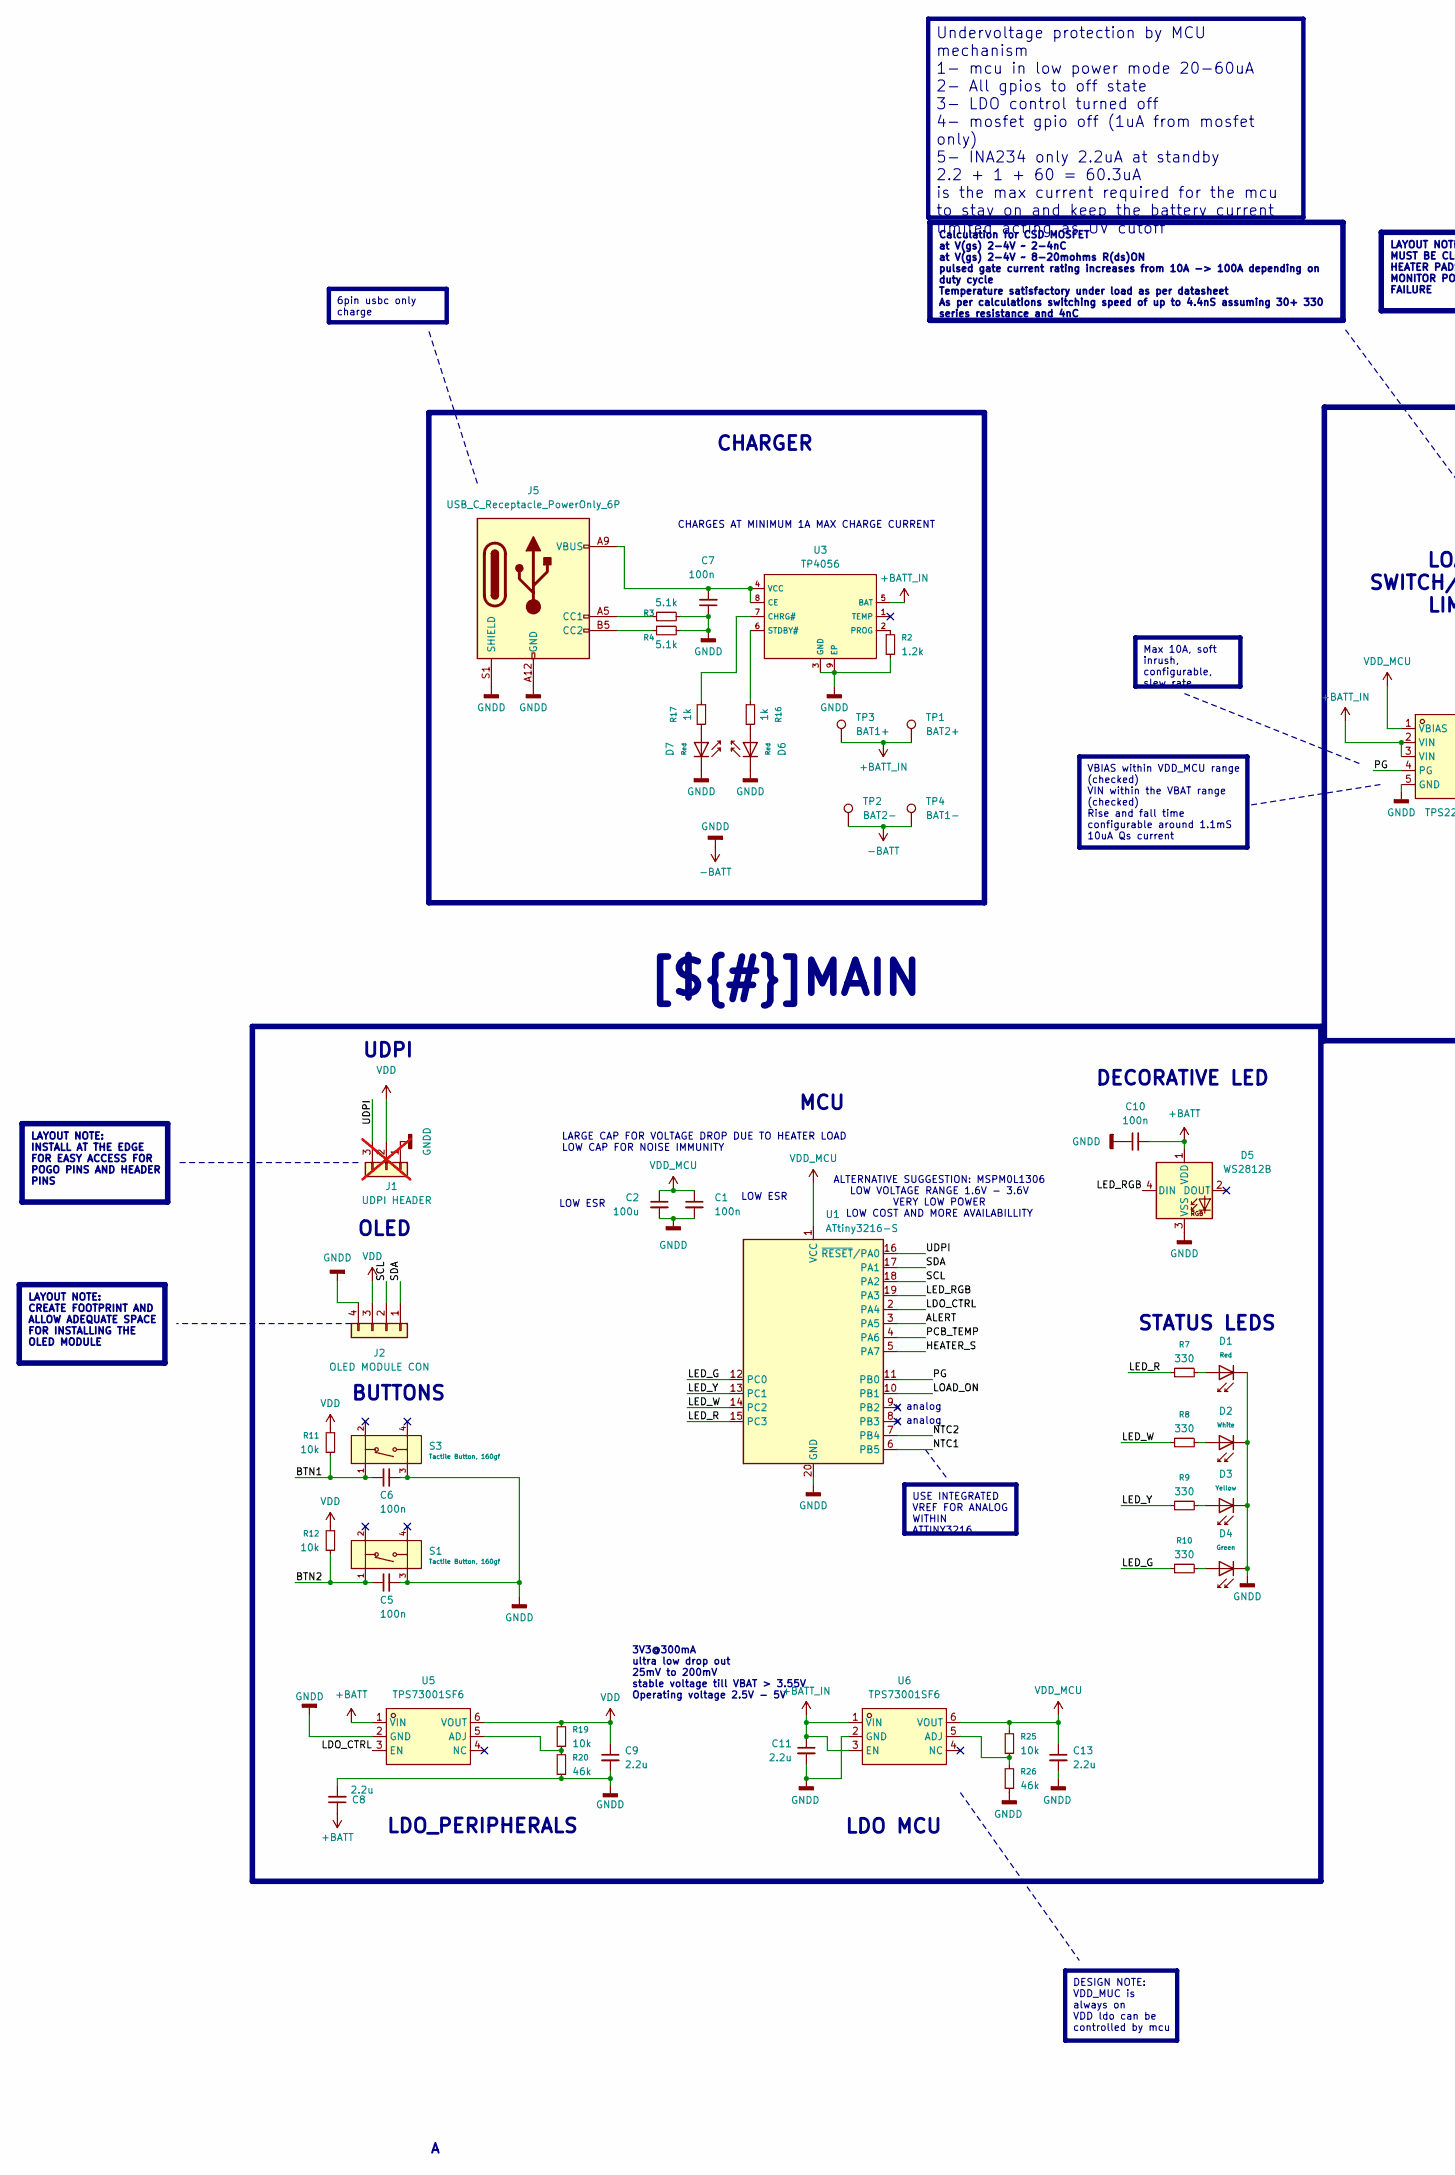
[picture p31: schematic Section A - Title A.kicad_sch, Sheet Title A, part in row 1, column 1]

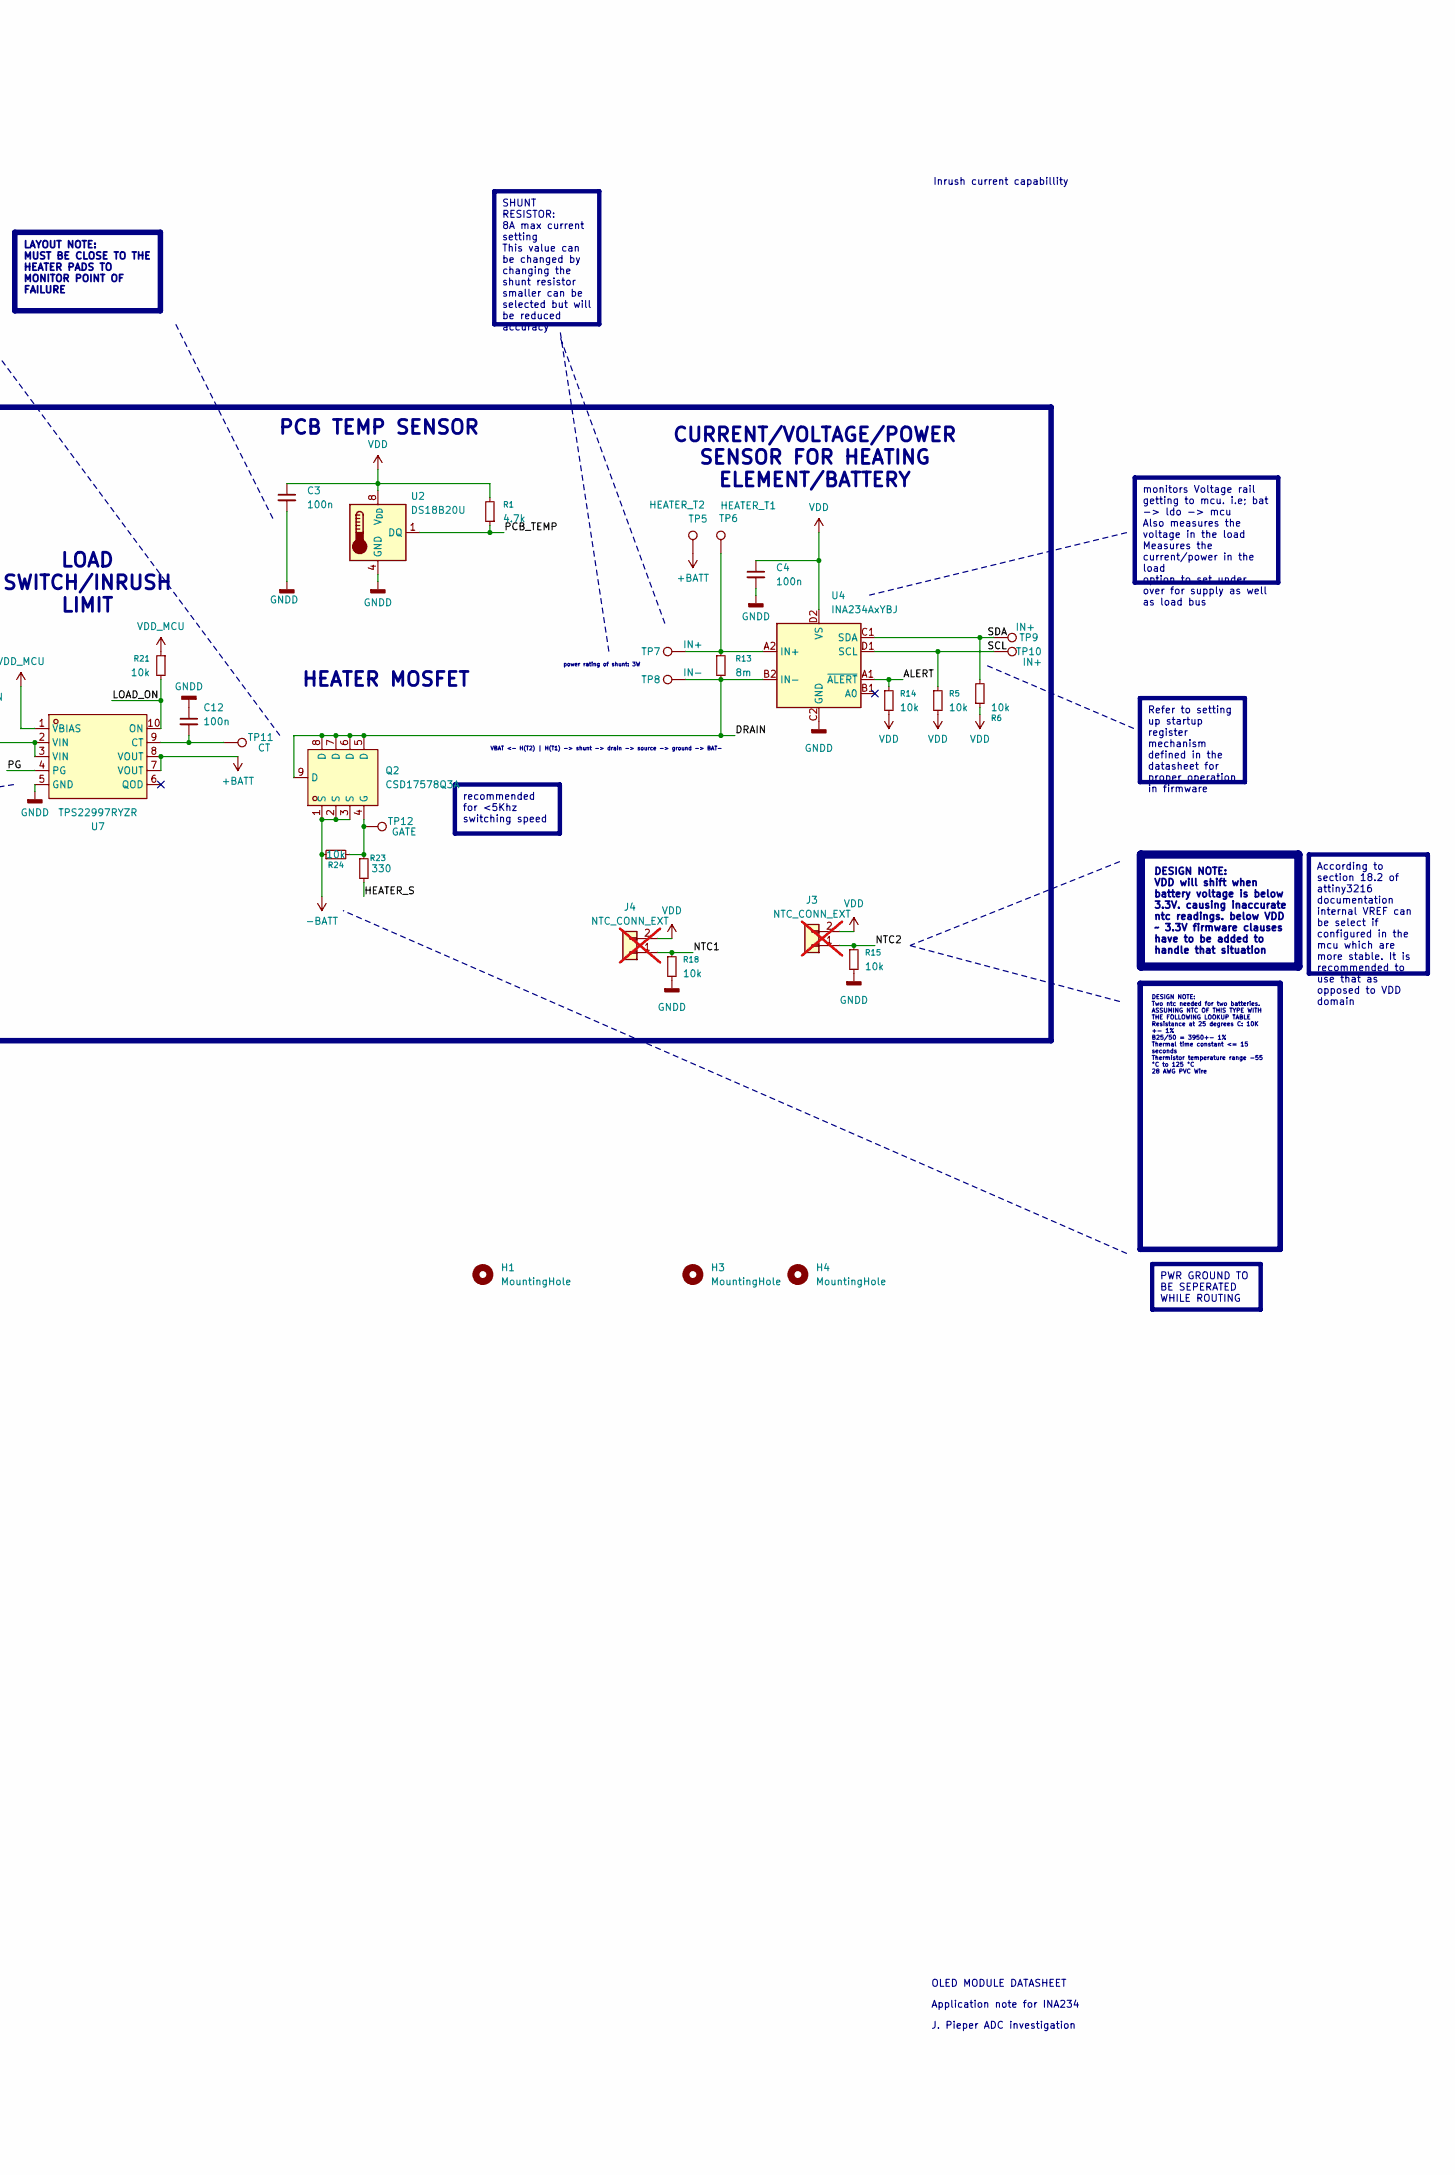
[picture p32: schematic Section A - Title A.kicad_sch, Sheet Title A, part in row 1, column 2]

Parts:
C1, C3, C4, C5, C6, C7, C10, C12: 100n; C_0402
C2: 100u; C_0805_2012Metric; LCSC C141660
C8, C9, C11, C13: 2.2u; C_0805_2012Metric
D1, D6, D7: Red; D_0603; Part KT-0603R; LCSC C2286
D2: White; D_0603; Part KT-0603W; LCSC C2290
D3: Yellow; D_0603; Forward Voltage (VF) 1.6V~2.6V; Part NCD0603Y2; LCSC C89811
D4: Green; D_0603; Part KT-0805G; LCSC C122984
D5: WS2812B; LED_WS2812B_PLCC4_5.0x5.0mm_P3.2mm; LCSC C22461793
H1, H3, H4: MountingHole; MountingHole_3mm
J1: UDPI HEADER; PinSocket_1x03_P2.54mm_Vertical; not fitted
J2: OLED MODULE CON; PinHeader_1x04_P2.54mm_Vertical
J3, J4: NTC_CONN_EXT; PinSocket_1x02_P2.54mm_Vertical; not fitted
J5: USB_C_Receptacle_PowerOnly_6P; USB_C_Receptacle_GCT_USB4135-GF-A_6P_TopMnt_Horizontal
Q2: CSD17578Q3A; PDFN3333-8_L3.1-W3.2-P0.65-LS3.4-BL; LCSC Part C205986
R1: 4.7k; R_0402_1005Metric
R2: 1.2k; R_0402_1005Metric
R3, R4: 5.1k; R_0402_1005Metric
R5, R6, R11, R12, R14, R15, R18, R19, R21, R24, R25: 10k; R_0402_1005Metric
R7, R8, R9, R10: 330; R_0402
R13: 8m; R_2512_6332Metric; LCSC C2904240
R16, R17: 1k; R_0402
R20, R26: 46k; R_0402_1005Metric; LCSC C3016791
R23: 330; R_0402_1005Metric
S1, S3: Tactile Button, 160gf; SW-SMD_4P-L5.1-W5.1-P3.70-LS6.5-TL-2; Voltage Rating (Dc) 12V; Part TS-1187A-B-A-B; LCSC C318884
TP1: BAT2+; TestPoint_Pad_D4.0mm
TP2: BAT2-; TestPoint_Pad_D4.0mm
TP3: BAT1+; TestPoint_Pad_D4.0mm
TP4: BAT1-; TestPoint_Pad_D4.0mm
TP5: HEATER_T2; TestPoint_Pad_D4.0mm
TP6: HEATER_T1; TestPoint_Pad_D4.0mm
TP7, TP9, TP10: IN+; TestPoint_THTPad_2.0x2.0mm_Drill1.0mm
TP8: IN-; TestPoint_THTPad_2.0x2.0mm_Drill1.0mm
TP11: CT; TestPoint_THTPad_2.0x2.0mm_Drill1.0mm
TP12: GATE; TestPoint_THTPad_2.0x2.0mm_Drill1.0mm
U1: ATtiny3216-S; SOIC-20W_7.5x12.8mm_P1.27mm
U2: DS18B20U; MSOP-8_3x3mm_P0.65mm
U3: TP4056; ESOP-8_L4.9-W3.9-P1.27-LS6.0-BL-EP; Part TP4056-42-ESOP8; LCSC C16581
U4: INA234AxYBJ; Texas_DSBGA-8_0.705x1.468mm_Layout2x4_P0.4mm
U5, U6: TPS73001SF6; SOT-23-6_L2.9-W1.6-P0.95-LS2.8-BL; LCSC Part C2915259
U7: TPS22997RYZR; UQFN-10_L2.0-W1.5-P0.50-TL; LCSC Part C17286840

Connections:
+BATT: C8.1, C10.2, D5.1 (VDD), TP5.1, U5.1 (VIN), U7.7 (VOUT), U7.8 (VOUT)
+BATT_IN: C11.1, TP1.1, TP3.1, U3.5 (BAT), U6.1 (VIN), U6.3 (EN), U7.2 (VIN), U7.3 (VIN)
-BATT: C1.2, C2.2, C3.2, C4.2, C5.2, C6.2, C7.1, C8.2, C9.2, C10.1, C11.2, C12.1, C13.2, D1.1, D2.1, D3.1, D4.1, D5.3 (VSS), D6.1, D7.1, J1.1, J2.4, J5.A12 (GND), J5.B12 (GND), J5.S1 (SHIELD), Q2.1 (S), Q2.2 (S), Q2.3 (S), R2.2, R3.2, R4.2, R15.2, R18.2, R20.1, R24.1, R26.1, S1.3 (C), S3.3 (C), TP2.1, TP4.1, U1.20 (GND), U2.4 (GND), U3.3 (GND), U3.9 (EP), U4.C2 (GND), U5.2 (GND), U6.2 (GND), U7.5 (GND)
/Project Architecture/Section A - Title A/ALERT: R14.1, U1.3 (PA5), U4.A1 (~ALERT)
/Project Architecture/Section A - Title A/BTN1: C6.1, R11.2, S3.1 (A)
/Project Architecture/Section A - Title A/BTN2: C5.1, R12.2, S1.1 (A)
/Project Architecture/Section A - Title A/DRAIN: Q2.5 (D), Q2.6 (D), Q2.7 (D), Q2.8 (D), Q2.9 (D), R13.2, TP8.1, U4.B2 (IN-)
/Project Architecture/Section A - Title A/HEATER_S: R23.2, U1.5 (PA7)
/Project Architecture/Section A - Title A/LDO_CTRL: U1.2 (PA4), U5.3 (EN)
/Project Architecture/Section A - Title A/LED_G: R10.1, U1.12 (PC0)
/Project Architecture/Section A - Title A/LED_R: R7.1, U1.15 (PC3)
/Project Architecture/Section A - Title A/LED_RGB: D5.4 (DIN), U1.19 (PA3)
/Project Architecture/Section A - Title A/LED_W: R8.1, U1.14 (PC2)
/Project Architecture/Section A - Title A/LED_Y: R9.1, U1.13 (PC1)
/Project Architecture/Section A - Title A/LOAD_ON: R21.2, U1.10 (PB1), U7.10 (ON)
/Project Architecture/Section A - Title A/NTC1: J4.1, R18.1, U1.6 (PB5)
/Project Architecture/Section A - Title A/NTC2: J3.1, R15.1, U1.7 (PB4)
/Project Architecture/Section A - Title A/PCB_TEMP: R1.1, U1.4 (PA6), U2.1 (DQ)
/Project Architecture/Section A - Title A/PG: U1.11 (PB0), U7.4 (PG)
/Project Architecture/Section A - Title A/SCL: J2.2, R5.1, TP10.1, U1.18 (PA2), U4.D1 (SCL)
/Project Architecture/Section A - Title A/SDA: J2.1, R6.2, TP9.1, U1.17 (PA1), U4.C1 (SDA)
/Project Architecture/Section A - Title A/UDPI: J1.3, U1.16 (~RESET/PA0)
unnamed: D1.2, R7.2
unnamed: D2.2, R8.2
unnamed: D3.2, R9.2
unnamed: D4.2, R10.2
unnamed: D6.2, R16.2
unnamed: D7.2, R17.2
unnamed: J5.A5 (CC1), R3.1
unnamed: J5.B5 (CC2), R4.1
unnamed: Q2.4 (G), R23.1, R24.2, TP12.1
unnamed: C7.2, J5.A9 (VBUS), J5.B9 (VBUS), U3.4 (VCC), U3.8 (CE)
unnamed: R17.1, U3.7 (CHRG#)
unnamed: R2.1, U3.2 (PROG)
unnamed: R16.1, U3.6 (STDBY#)
unnamed: R13.1, TP6.1, TP7.1, U4.A2 (IN+)
unnamed: R19.1, R20.2, U5.5 (ADJ)
unnamed: R25.1, R26.2, U6.5 (ADJ)
unnamed: C12.2, TP11.1, U7.9 (CT)
VDD: C3.1, C4.1, C9.1, J1.2, J2.3, J3.2, J4.2, R1.2, R5.2, R6.1, R11.1, R12.1, R14.2, R19.2, U2.8 (V_{DD}), U4.D2 (VS), U5.6 (VOUT)
VDD_MCU: C1.1, C2.1, C13.1, R21.1, R25.2, U1.1 (VCC), U6.6 (VOUT), U7.1 (VBIAS)

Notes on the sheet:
3V3@300mA ultra low drop out 25mV to 200mV stable voltage till VBAT > 3.55V Operating voltage 2.5V - 5V
VBAT <- H(T2) | H(T1) -> shunt -> drain -> source -> ground -> BAT-
x analog
LOW ESR
ALTERNATIVE SUGGESTION: MSPM0L1306 LOW VOLTAGE RANGE 1.6V - 3.6V VERY LOW POWER LOW COST AND MORE AVAILABILLITY
Inrush current capabillity
CHARGES AT MINIMUM 1A MAX CHARGE CURRENT
J. Pieper ADC investigation
LARGE CAP FOR VOLTAGE DROP DUE TO HEATER LOAD LOW CAP FOR NOISE IMMUNITY
power rating of shunt: 3W
Application note for INA234
OLED MODULE DATASHEET
DESIGN NOTE: VDD will shift when battery voltage is below 3.3V. causing inaccurate ntc readings. below VDD ~ 3.3V firmware clauses have to be added to handle that situation
DECORATIVE LED
LDO_PERIPHERALS
UDPI
VBIAS within VDD_MCU range (checked) VIN within the VBAT range (checked) Rise and fall time configurable around 1.1mS 10uA Qs current
LDO MCU
CURRENT/VOLTAGE/POWER SENSOR FOR HEATING ELEMENT/BATTERY
BUTTONS
STATUS LEDS
LAYOUT NOTE: CREATE FOOTPRINT AND ALLOW ADEQUATE SPACE FOR INSTALLING THE OLED MODULE
6pin usbc only charge
Max 10A, soft inrush, configurable, slew rate
PWR GROUND TO BE SEPERATED WHILE ROUTING
Refer to setting up startup register mechanism defined in the datasheet for proper operation in firmware
DESIGN NOTE: VDD_MUC is always on VDD ldo can be controlled by mcu
Undervoltage protection by MCU mechanism 1- mcu in low power mode 20-60uA 2- All gpios to off state 3- LDO control turned off 4- mosfet gpio off (1uA from mosfet only) 5- INA234 only 2.2uA at standby 2.2 + 1 + 60 = 60.3uA is the max current required for the mcu to stay on and keep the battery curre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
HEATER MOSFET
LOAD SWITCH/INRUSH LIMIT
LAYOUT NOTE: INSTALL AT THE EDGE FOR EASY ACCESS FOR POGO PINS AND HEADER PINS
monitors Voltage rail getting to mcu. i.e; bat -> ldo -> mcu Also measures the voltage in the load Measures the current/power in the load option to set under, over for supply as well as load bus
SHUNT RESISTOR: 8A max current setting This value can be changed by changing the shunt resistor smaller can be selected but will be reduced accuracy
USE INTEGRATED VREF FOR ANALOG WITHIN ATTINY3216
CHARGER
PCB TEMP SENSOR
[${#}]MAIN
DESIGN NOTE: Two ntc needed for two batteries. ASSUMING NTC OF THIS TYPE WITH THE FOLLOWING LOOKUP TABLE Resistance at 25 degrees C: 10K +- 1% B25/50 = 3950+- 1% Thermal time constant <= 15 seconds Thermistor temperature range -55 °C to 125 °C 28 AWG PVC Wire
recommended for <5Khz switching speed
MCU

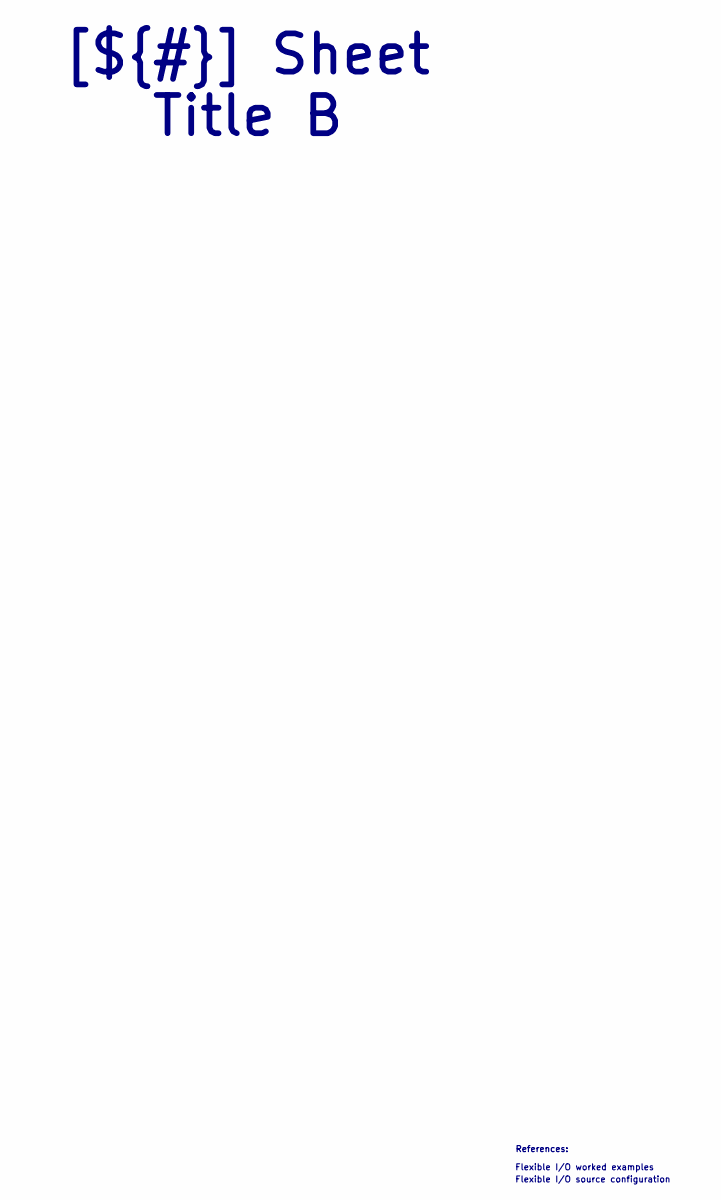
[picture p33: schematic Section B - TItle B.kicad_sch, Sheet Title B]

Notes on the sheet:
Flexible I/O worked examples
References:
Flexible I/O source configuration
[${#}] ${TITLE}

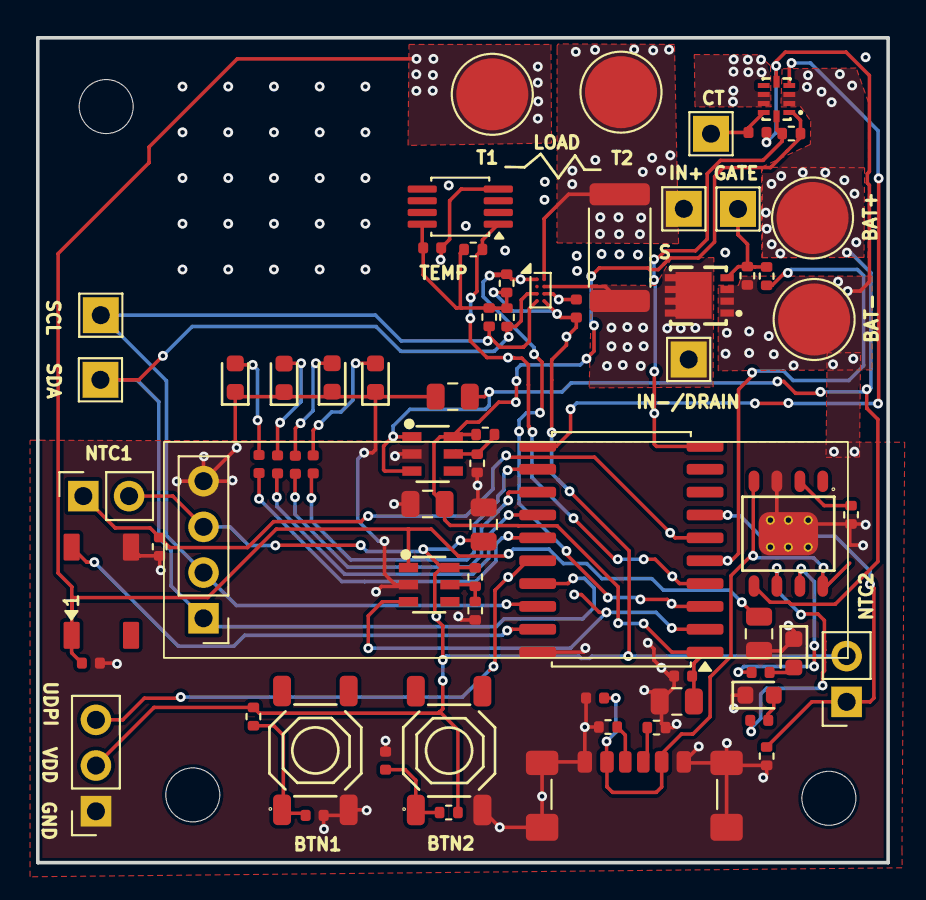
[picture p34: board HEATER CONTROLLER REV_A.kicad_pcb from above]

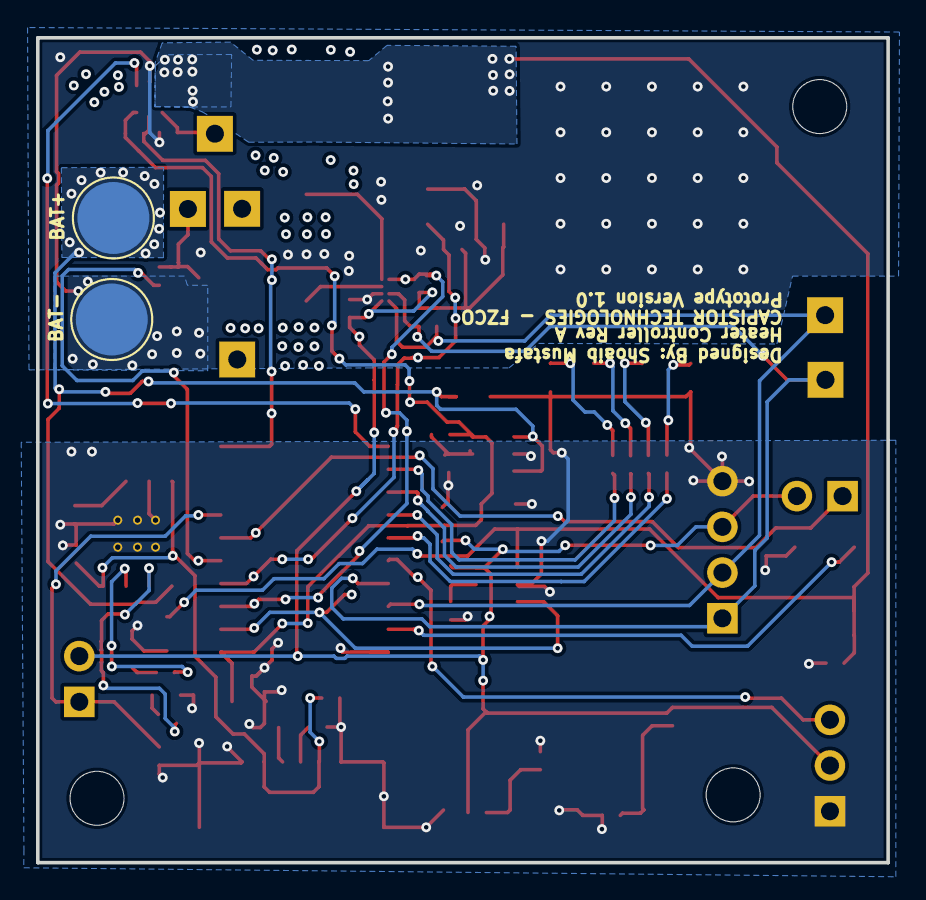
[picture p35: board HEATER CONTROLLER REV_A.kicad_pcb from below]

Board: 2 copper layers, 47.2 x 45.8 mm, 75 parts (2 on the bottom side), 41 nets.

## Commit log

2026-05-18 Initial backup: schematic, PCB, renders, BOM
    [Block Diagram.kicad_sch, HEATER CONTROLLER REV_A.dsn, HEATER CONTROLLER REV_A.kicad_pcb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]
2026-05-18 Enrich README: schematic PNG, component roles, BOM table
